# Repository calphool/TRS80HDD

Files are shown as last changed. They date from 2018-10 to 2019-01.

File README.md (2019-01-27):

# TRS80HDD
Repo for TRS-80 Model 1 Drive emulator project

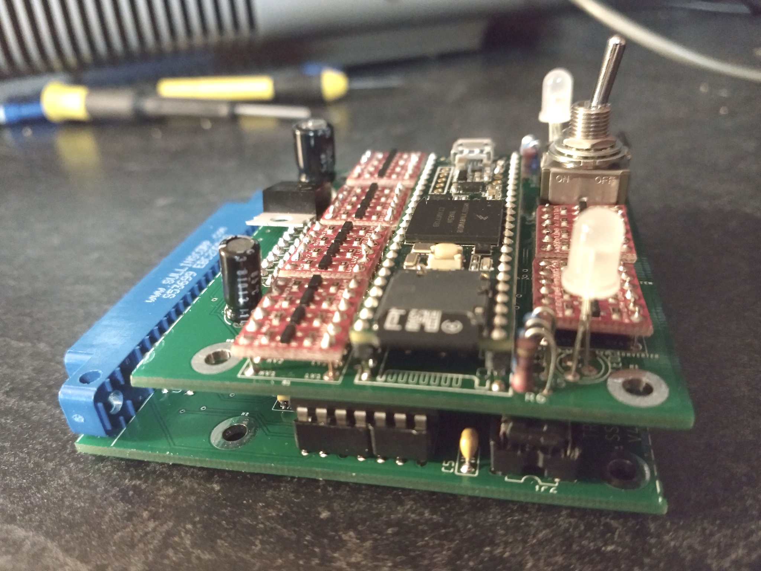
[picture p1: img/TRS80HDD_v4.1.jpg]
Version 4.1 of PCB


Here we go again.  So after I finished the graphics/sound/communications card, I started working on a new
project.  This time I'm working on interfacing the TRS-80 to a Teensy 3.6, which is an Arduino-ish microcontroller 
board.  It's a lot faster than the Arduino Uno, and has more ports.  You can use the Arduino tool chain, which is 
nice. 

Theory of Operation
===================

To understand how this card works (in theory... still working out some bugs as of December 2018), you have to 
understand how the TRS-80 expected to interface to floppy drives.  I'm in awe of what engineers in 1977 had to 
deal with to produce a working computer.  We take so much for granted today.  First of all, the TRS-80 Model 1
couldn't interface to a floppy drive unless you purchased the Expansion System.  That expansion system is 
essentially a large daughter board and a power supply.  It connected to your TRS-80 via a ribbon cable attached 
to the expansion bus on the keyboard/CPU unit.  Inside was a fairly complex set of components.  There's a real time
clock module that keeps pinging the CPU unit 40 times a second.  There's additional DRAM in there.  There's a bunch
of glue logic that allows you to connect a parallel port printer (remember those?) and a UART for (very slow) 
RS232 / modem connectivity.  Finally, there's an [FD1771](https://en.wikipedia.org/wiki/Western_Digital_FD1771) chip.
That chip is one of the first floppy disk controller chips.  It was released in 1976, and was used in various forms 
up into the 1990s.  On one side of the chip you've got an interface designed to connect to a system bus, and on the 
other side you've got an interface designed to connect to a stepper driven floppy drive.  There's glue logic in the 
Expansion System that basically memory mapped the FD1771 chip into the address space of the Z80 processor of the 
CPU unit.  You get a little keyhole interface into RAM (0x37E0 - 0x37EF) that you can read and write to, and the chip 
responds by reading/writing to the floppy by manipulating the drive spindle and the head steppers.

So, the way this emulated device works is that it has an address decoder that watches for those addresses, along with 
read and write signal lines, triggers a flip-flop that puts the Z80 processor in the CPU unit into a WAIT state, 
invokes an interrupt on the Teensy, the Teensy reads an SD card for a disk image, and emulates the intent of the 
read or write command against that disk image file.  Once the read or write is complete the Teensy kicks the flip-flop 
and the WAIT state is released.  ~~At least, that's the theory.  I'm still working through some timing issues before 
I start working in earnest on the Teensy code.  Basically I've got everything working right now except the data bus.
The data bus seems to be doing nothing at the moment, and I haven't figured out exactly what's wrong yet.~~

Build Notes
===========

January 26, 2019

Well, I bodged a 32k SRAM onto the design.  Some NEWDOS games won't work because they expect (quite reasonably) that you have 48k of RAM,
since the original TRS-80 expansion system included some RAM, and you couldn't really run a disk drive without having the extra RAM.  
Version 4.2 of the schematic and board include this enhancement.

So here's what I'm thinking about doing... I'm thinking about designing a set of three stackable boards (sort of like Arduino shields).  The 
first board just gives you 32k of extra RAM, six channel (+2 noise) audio, and your power supply.  The second adds the TMS9118 video 
(see TRS80GS) and joystick ports. The third adds the emulated disk drive.  So, you could build these boards and then snap them together as you like.

January 22, 2019

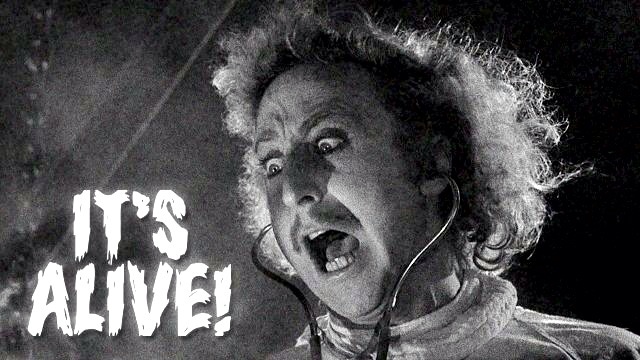
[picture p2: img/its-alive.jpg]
It's Alive!


Holy smokes.  [It's working.](https://www.youtube.com/watch?v=pcdh7HSC1nE)  I've got NEWDOS/80 v2 booting up, and it seems quite functional.  
Since I haven't implemented WRITE handling code, and only the most critical READ handling code, it's pretty fragile right now, but it's booting 
and responding to commands.  This is the v4 board, so if you're following along and want to make your own, v4 with current code is the first 
actually functioning configuration.  

January 16, 2019

Considerable gnashing of teeth has occurred over the past month, but progress has been made.  The v3 and v3.1 designs 
are basically a bust.  There has been some kind of race condition on the WR* side of the data bus, and figuring out what
was going on has been nontrivial.  Folks on the Teensy forum basically said that the problem was that I was using 
unrelated Teensy ports for my 8 data signals, and that digitalReadFast() wasn't fast enough when you used it that way.
So they suggested I redesign the circuit so that all the data lines reside in a single Teensy port, which I did....
and it made absolutely no difference... Luckily I didn't completely trust their diagnosis and I simultaneously created the 
v4 design.  The v4 design was intended to fix the race condition by implementing a latch on the 
data bus (more or less a classical output port design).  This did improve things (actually started getting data to the 
Teensy sometimes), but it wasn't reliable.  After a lot of hand wringing, someone on the Teensy forums suggested a slight 
change to my wait flip flop triggering circuit so that it triggered as soon as an interesting address appeared (as soon 
as the 37EX signal toggled) rather than waiting for both that *and* a RD* or WR* signal.  This made the circuit fairly 
predictable, though it still glitches about 1 out of every 1000 writes.  The design is available in schematic v4.1.
I'm thinking that perhaps if I swap out all the LS series chips with ALS series chips, I'll get just enough of a 
performance boost across the combined propogation delay that I can get the WR* side rock solid like the RD* side is.  We'll
see.

However, the good news is that I'm actually booting stuff now.

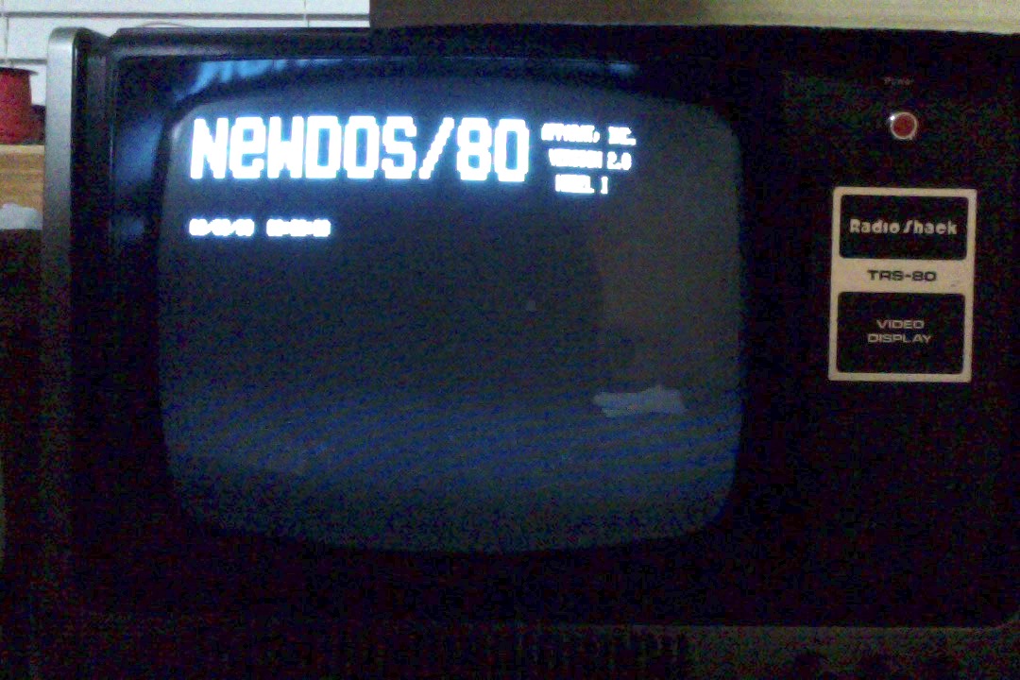
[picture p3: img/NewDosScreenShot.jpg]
NEWDOS screen shot


~~There's still *some* kind of bug in my emulation, because it gets loaded and then doesn't give me control, and keeps 
trying to reload.  I know that the problem is somehow related to the clock signal, because when I shut it off it loads and
then just sits there.  If I turn it on, it loads, and then reloads, in a loop.  So I'm guessing I need to do something 
besides just turn the clock on, but I don't know what it's expecting just yet.  It could be as simple as making sure that
I'm handling the FD1771 status register correctly when I get to the end of the boot cycle.  I do think I've got a few bugs left 
in the status register handling, and I think I might have an off-by-one problem in handling sector read commands.  So either 
one of those problems could be the source of my rebooting problem.  However, I'm really close, and that makes me super happy.~~

With some help from someone on reddit, I was able to get it booting.  It's related to the fact that I'm using JV1 disk images, 
which apparently don't encode all the data that was on the original disks.  Apparently part of what was missing was a code that 
can be returned in the status register that indicates to the operating system that what it's reading represents directory data.
Since my disk images don't have that info, I guess my code is supposed to assume track 17 is the directory data, so it was 
as simple as forcing the status register to OR 0x20 with whatever it's already doing if the track is 17.

It's still not quite working right, because I can't do a DIR command (says "device not available"), but it's booting and semi-
usable now.  Now I just need to figure out why I can't do a DIR command.  I'm beginning to wonder if I shouldn't just figure 
out how to port the applicable code from SDLTRS over to the Teensy.  Then I'd be able to support several disk formats, and 
these kinds of strange little details would be handled for me, rather than me slowly finding them one by one.  I've avoided 
trying the port exercise, because I wasn't sure if the C compilers are compatible, or if I'll end up with strange data size 
issues or endian issues.  I might make one quick stab at getting it working without the porting effort, and then if it doesn't
work I'll dive into that.

--------------------------------------------------------

December 17, 2018

Well I'm working on version 2 of this project.  I found a copy of Byte Magazine from the late 70s that included a 
schematic from Steve Ciarcia for his Disk-80 project.  I decided to abandon my home grown address decoder and 
switched to his design.  The v3 of the schematic represents that.  Upon assembly, it didn't really work, and I 
was scratching my head.  I reached out to Peter Bartlett, who is the rock star that designed the MISE and M3SE 
boards that are light years beyond what my little projects are capable of.  He took a look at my schematics and 
helped me realize that I used a 74LS241 for my data buffer, and I probably meant to use a 74LS244.  The difference 
is that 74LS241 has four bits that are controlled by a positive enable pin, and the other four are controlled by 
a negative enable pin.  So I ordered some 74LS244's and we'll see where that gets me.

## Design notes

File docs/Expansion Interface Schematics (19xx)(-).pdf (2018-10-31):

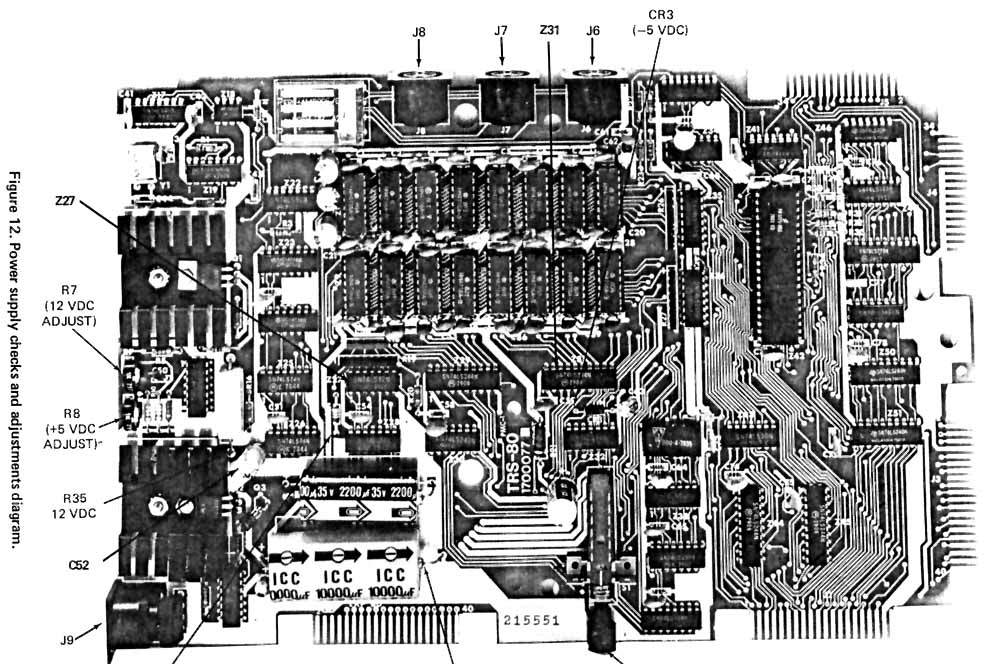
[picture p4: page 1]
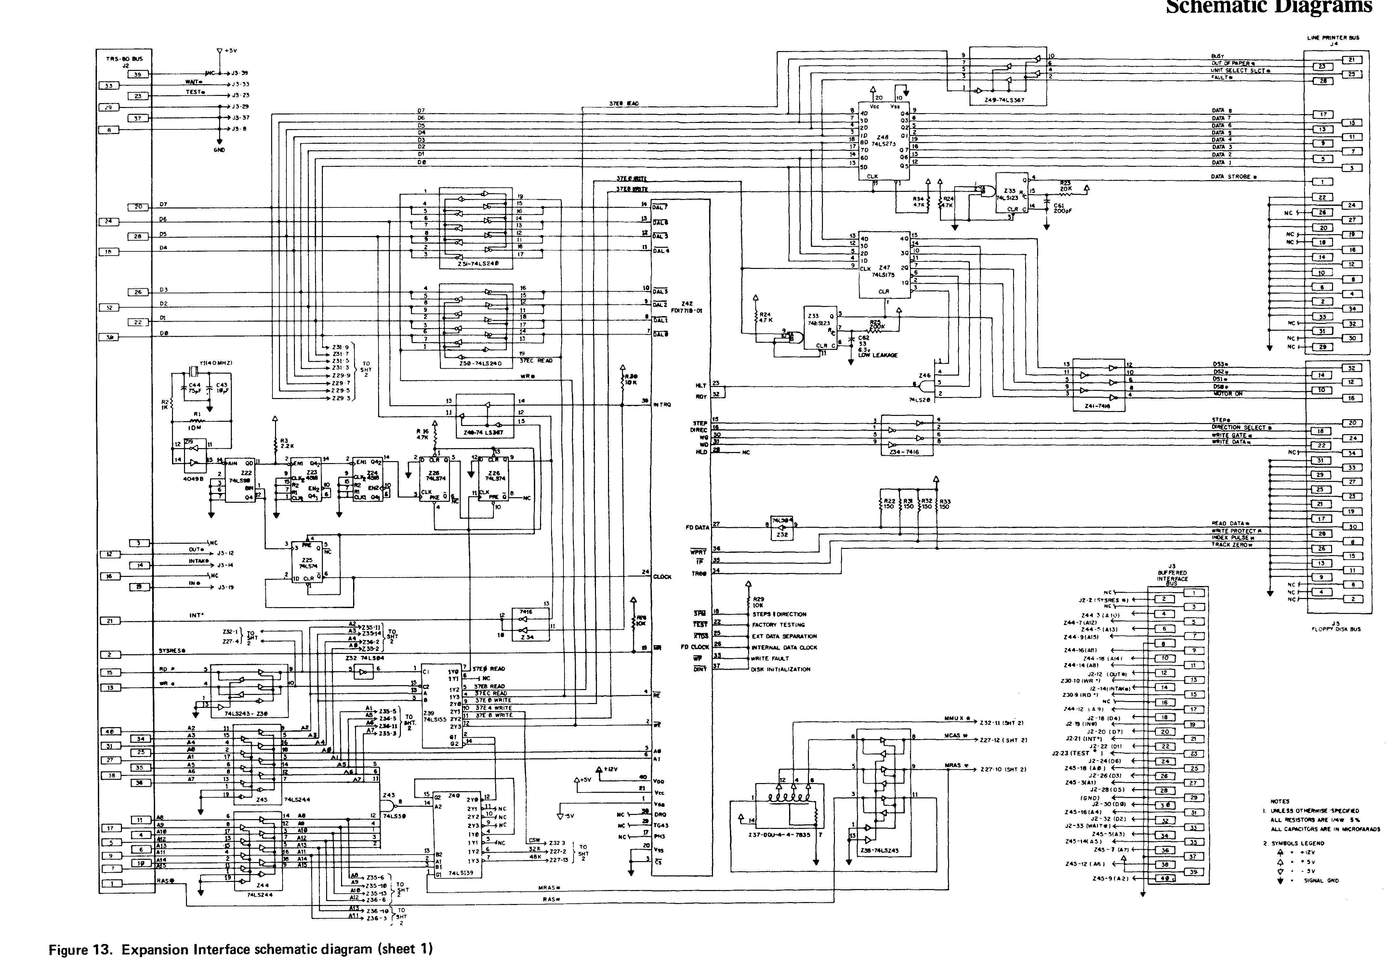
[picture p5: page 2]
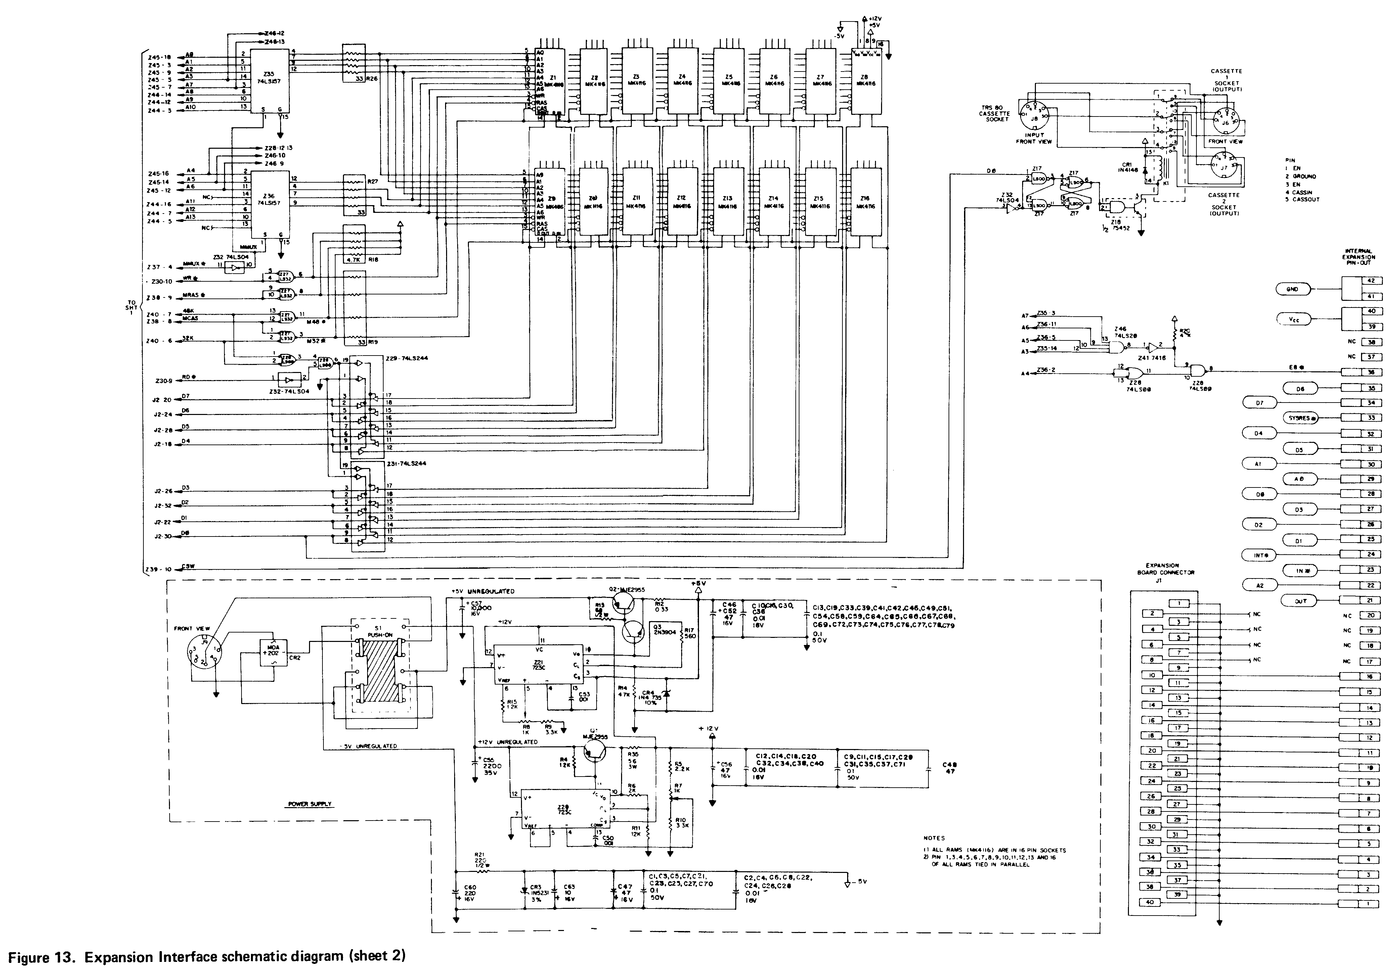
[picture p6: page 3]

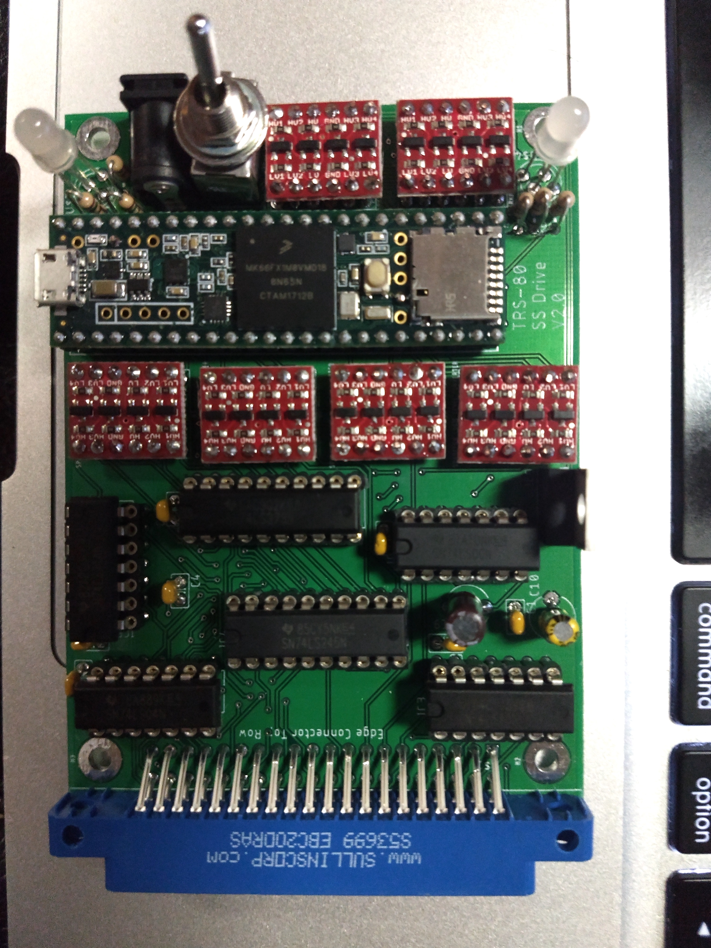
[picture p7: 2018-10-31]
img/TRS80HDD_v2.jpg

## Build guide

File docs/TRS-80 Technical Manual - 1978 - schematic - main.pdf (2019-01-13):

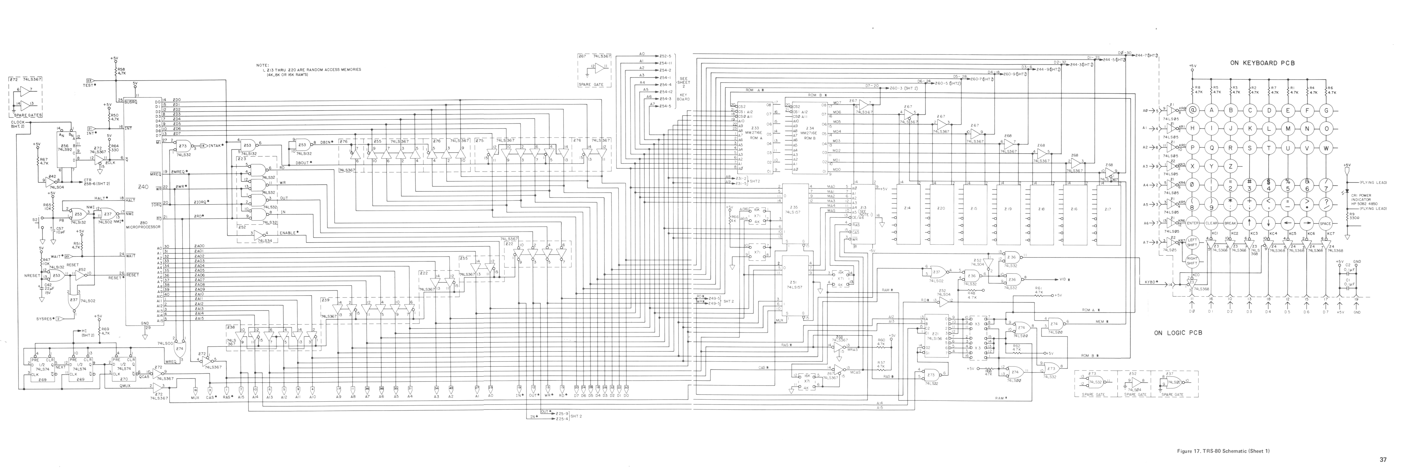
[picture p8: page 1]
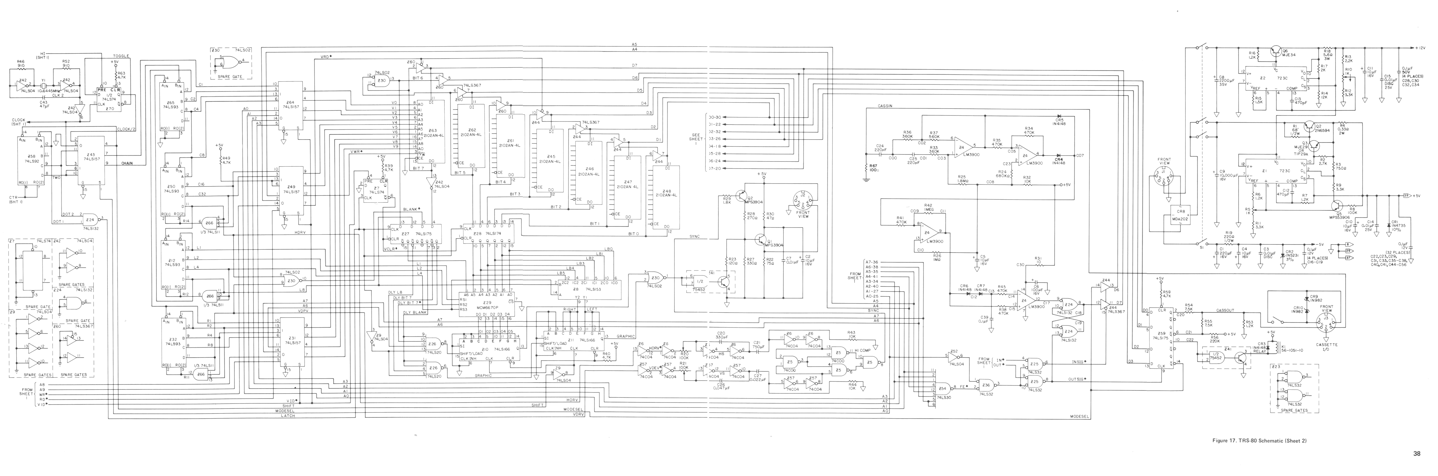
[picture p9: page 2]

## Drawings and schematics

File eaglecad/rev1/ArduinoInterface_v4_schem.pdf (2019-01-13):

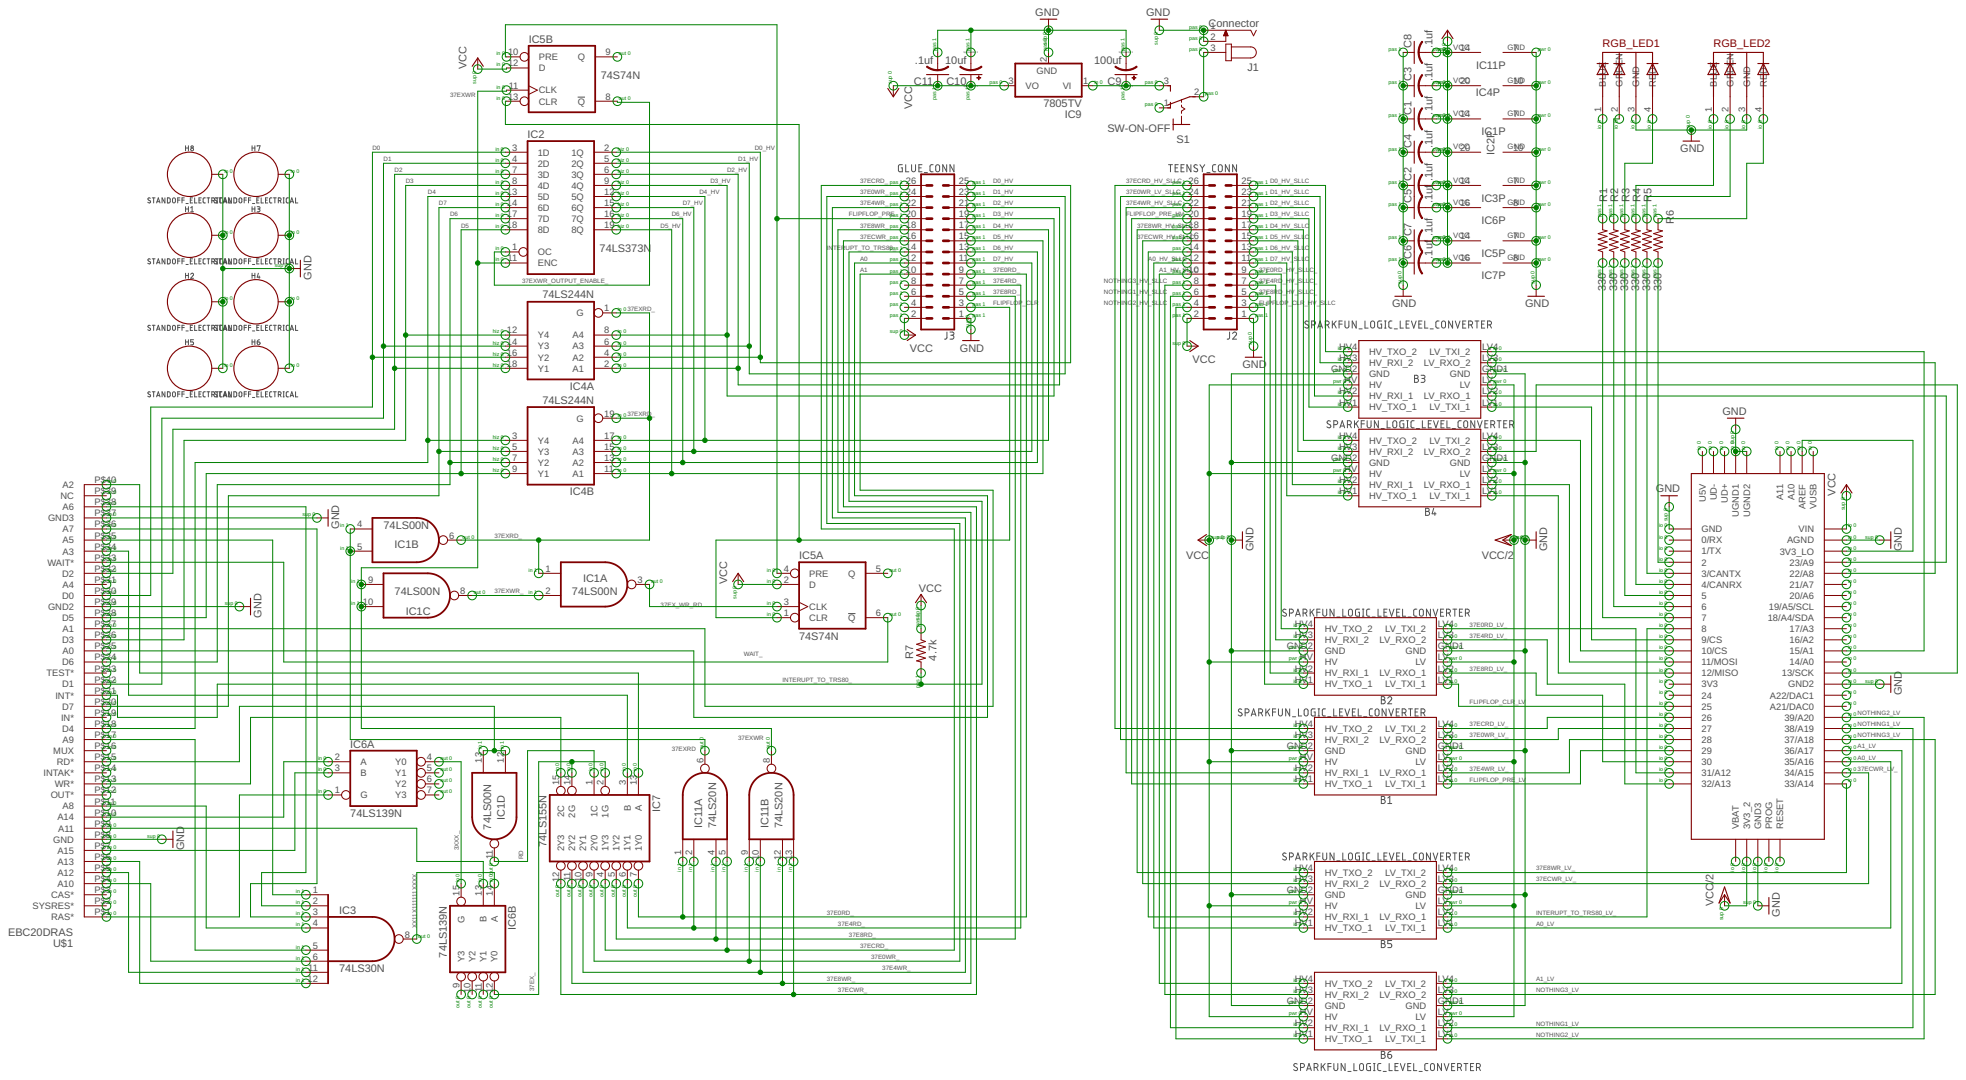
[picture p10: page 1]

D2 | 7 in 0 | 6 hiz 0 | D2_HV
D3 | 8 in 0 | 9 hiz 0 | D3_HV

14 hiz 0 | 6 A4 in 0
16 hiz 0 | | 4 A3 in 0
18 hiz 0 | | 2 A2 in 0

io 0 sup 0

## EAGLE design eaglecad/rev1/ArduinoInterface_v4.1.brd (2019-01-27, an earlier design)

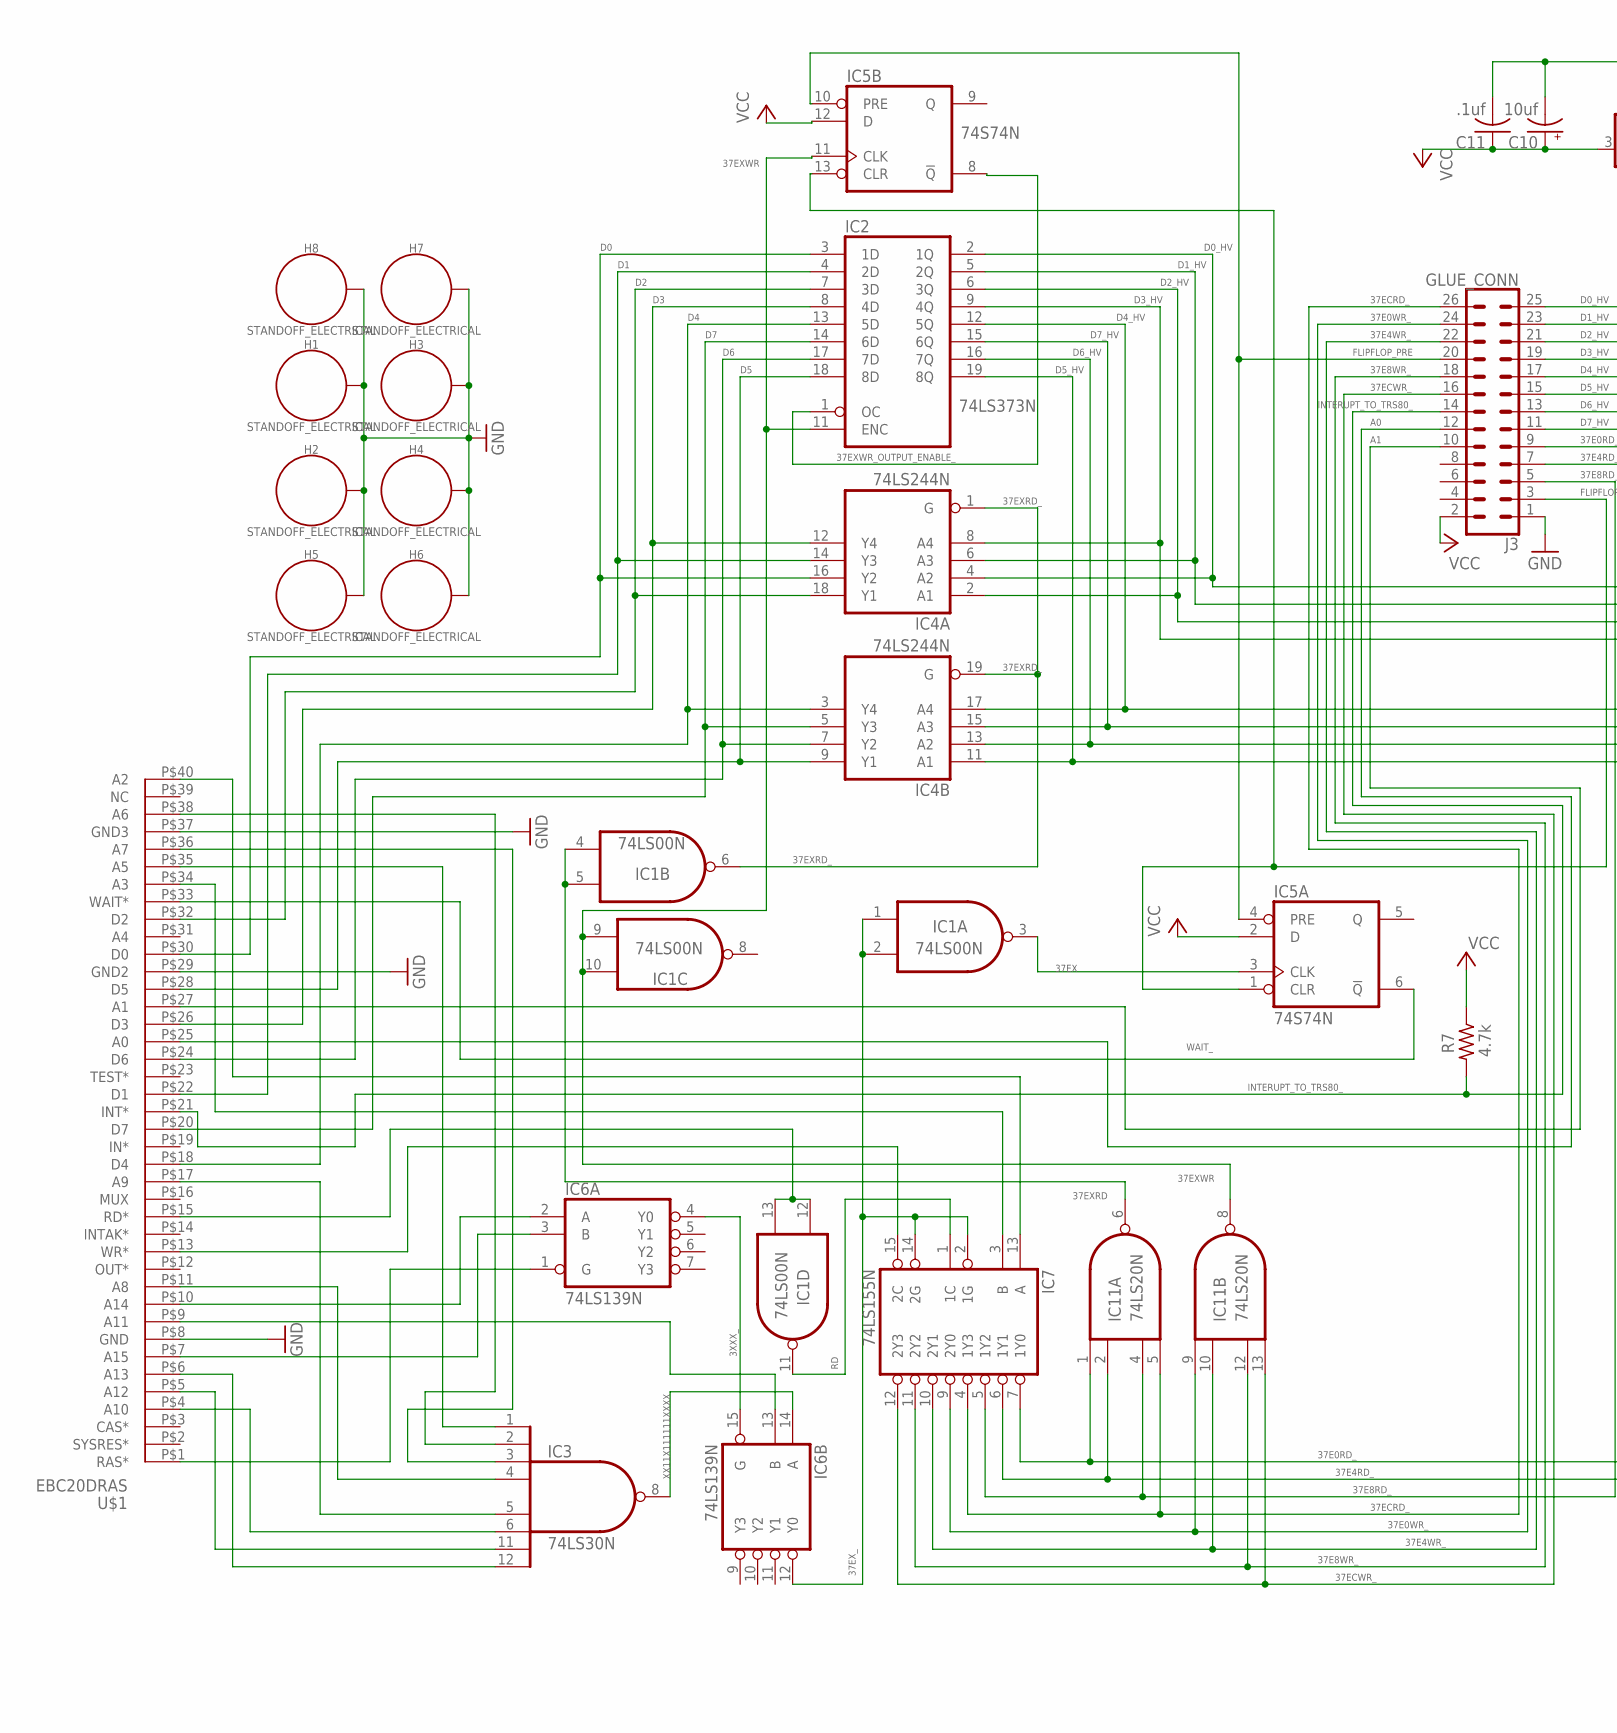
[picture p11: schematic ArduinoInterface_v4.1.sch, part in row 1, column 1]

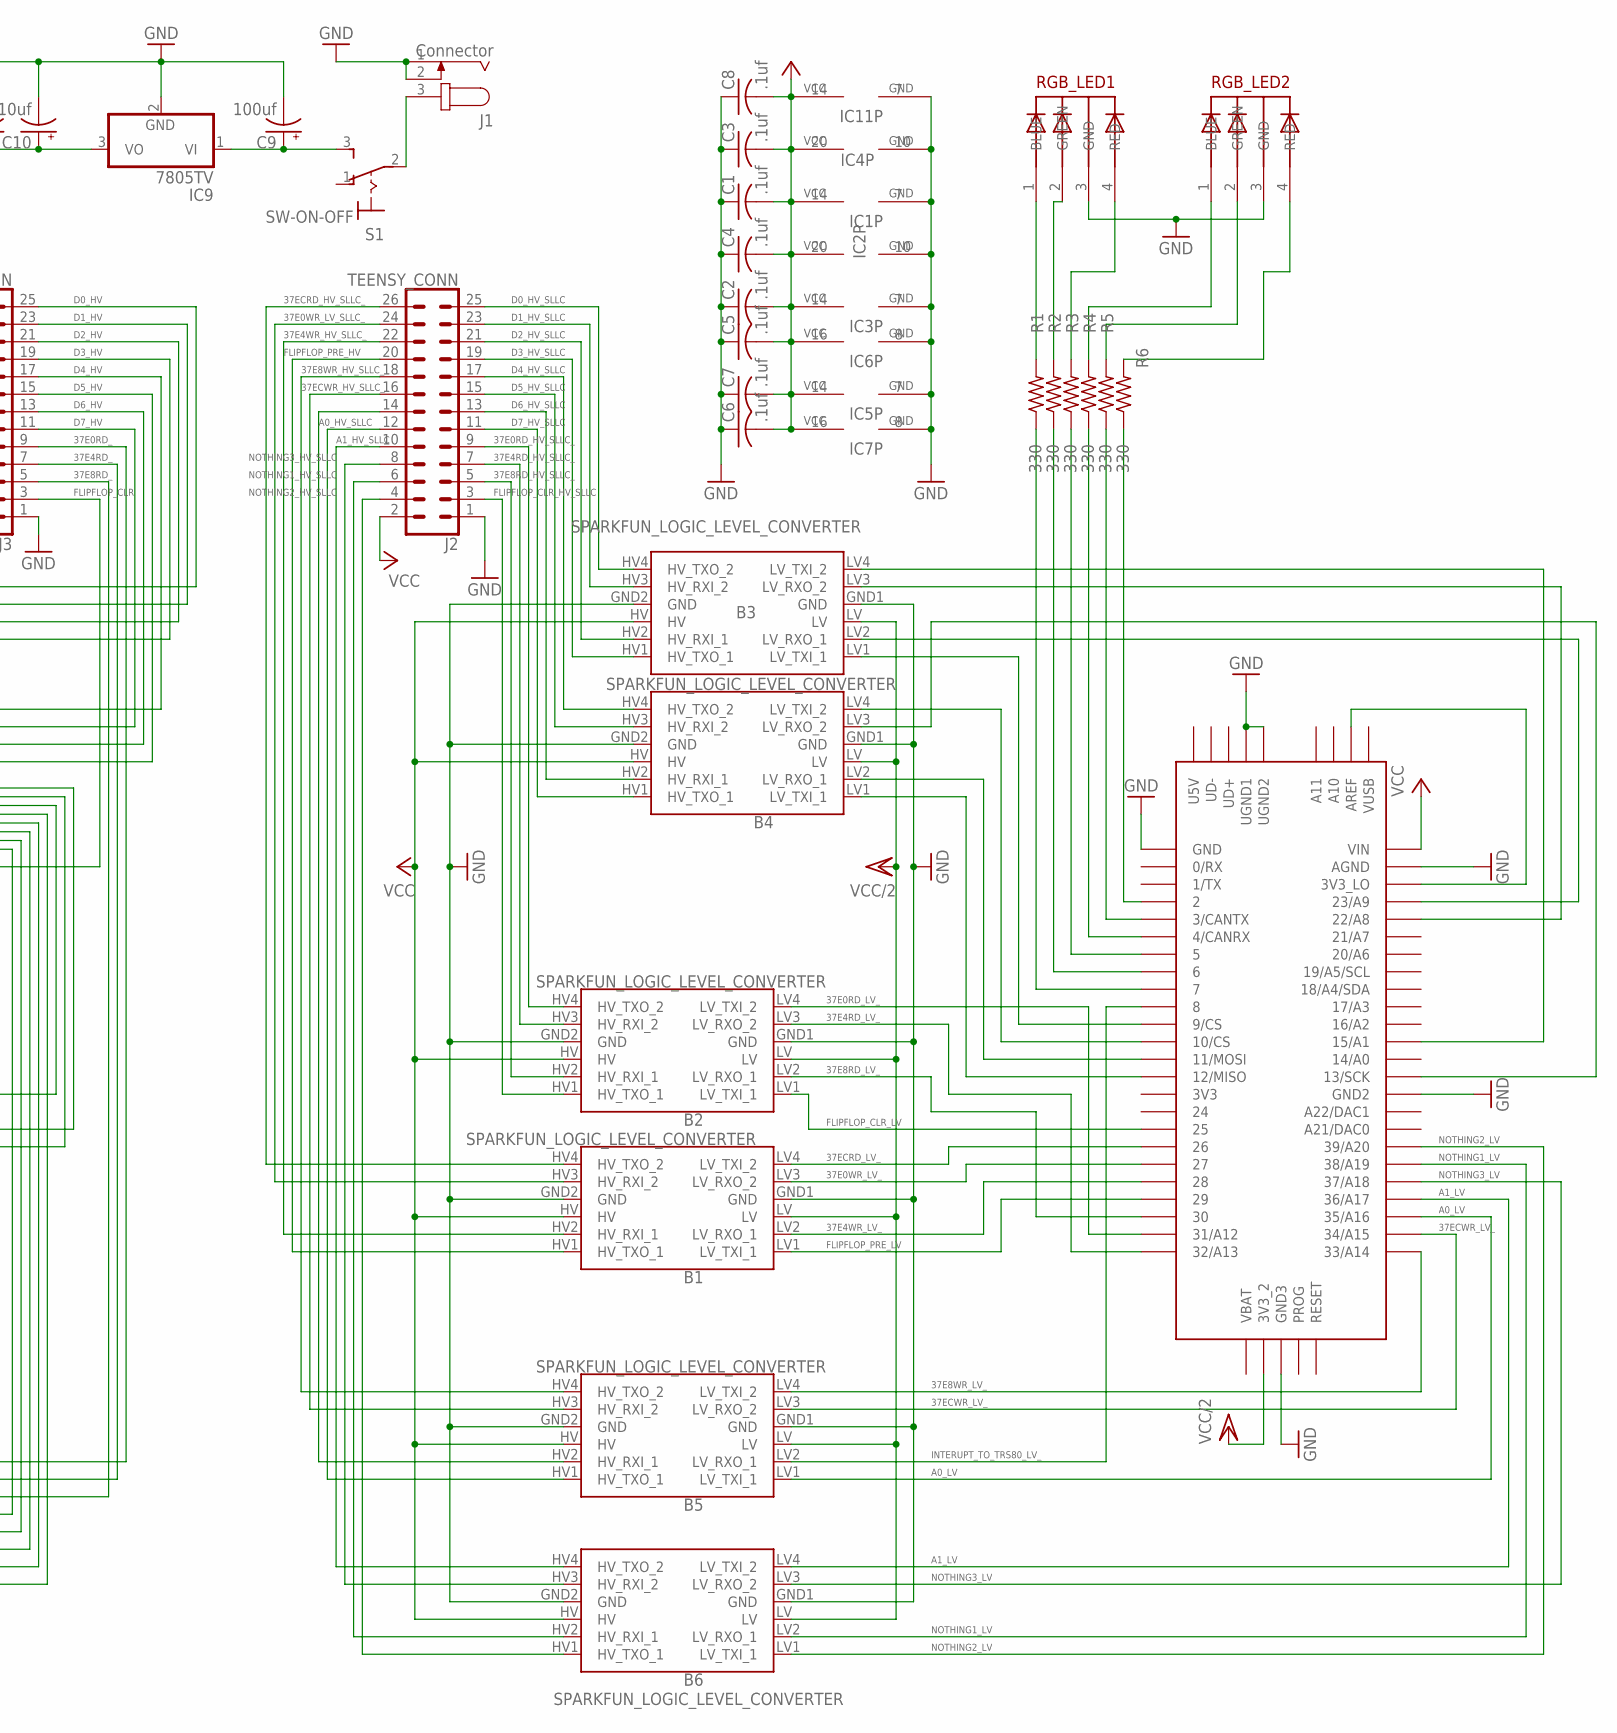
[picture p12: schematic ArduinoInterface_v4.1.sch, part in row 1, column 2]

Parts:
B1, B2, B3, B4, B5, B6: SPARKFUN_LOGIC_LEVEL_CONVERTER
C1, C2, C3, C4, C5, C6, C7, C8, C11: .1uf; C025-025X050
C9: 100uf; E5-6
C10: 10uf; E5-6
H1, H2, H3, H4, H5, H6, H7, H8: STANDOFF_ELECTRICAL; STANDOFF-ELECTRICAL
IC1: 74LS00N; DIL14
IC2: 74LS373N; DIL20
IC3: 74LS30N; DIL14
IC4: 74LS244N; DIL20
IC5: 74S74N; DIL14
IC6: 74LS139N; DIL16
IC7: 74LS155N; DIL16
IC9: 7805TV; TO220V
IC11: 74LS20N; DIL14
J1: Connector; SPC4077
J2: TEENSY_CONN; 2X13
J3: GLUE_CONN; 2X13
R1, R2, R3, R4, R5, R6: 330; 0204V
R7: 4.7k; 0204V
RGB_LED1, RGB_LED2: 5MMRGBLED; LED5MMRGB
S1: SW-ON-OFF; M9040P
U$1: EBC20DRAS
U$2: TEENSY_3.5/3.6

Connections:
3XXX_: IC6.4 (Y0), IC6.15 (G)
9V: C9.+, IC9.1 (VI), S1.3 (S)
9V_TO_SW: J1.3, S1.2
37E0RD_: IC7.7 (1Y0), IC11.1 (I0), J3.9
37E0RD_HV_SLLC_: B2.HV4 (HV_TXO_2), J2.9
37E0RD_LV_: B2.LV4 (LV_TXI_2), U$2.31/A12
37E0WR_: IC7.9 (2Y0), IC11.9 (I0), J3.24
37E0WR_LV_: B1.LV3 (LV_RXO_2), U$2.27
37E0WR_LV_SLLC_: B1.HV3 (HV_RXI_2), J2.24
37E4RD_: IC7.6 (1Y1), IC11.2 (I1), J3.7
37E4RD_HV_SLLC_: B2.HV3 (HV_RXI_2), J2.7
37E4RD_LV_: B2.LV3 (LV_RXO_2), U$2.32/A13
37E4WR_: IC7.10 (2Y1), IC11.10 (I1), J3.22
37E4WR_HV_SLLC_: B1.HV2 (HV_RXI_1), J2.22
37E4WR_LV_: B1.LV2 (LV_RXO_1), U$2.28
37E8RD_: IC7.5 (1Y2), IC11.4 (I2), J3.5
37E8RD_HV_SLLC_: B2.HV2 (HV_RXI_1), J2.5
37E8RD_LV_: B2.LV2 (LV_RXO_1), U$2.30
37E8WR_: IC7.11 (2Y2), IC11.12 (I2), J3.18
37E8WR_HV_SLLC_: B5.HV4 (HV_TXO_2), J2.18
37E8WR_LV_: B5.LV4 (LV_TXI_2), U$2.33/A14
37ECRD_: IC7.4 (1Y3), IC11.5 (I3), J3.26
37ECRD_HV_SLLC_: B1.HV4 (HV_TXO_2), J2.26
37ECRD_LV_: B1.LV4 (LV_TXI_2), U$2.26
37ECWR_: IC7.12 (2Y3), IC11.13 (I3), J3.16
37ECWR_HV_SLLC_: B5.HV3 (HV_RXI_2), J2.16
37ECWR_LV_: B5.LV3 (LV_RXO_2), U$2.34/A15
37EX: IC1.3 (O), IC5.3 (CLK)
37EXRD: IC1.4 (I0), IC1.5 (I1), IC11.6 (O)
37EXRD_: IC1.6 (O), IC4.1 (G), IC4.19 (G)
37EXWR: IC1.9 (I0), IC1.10 (I1), IC2.11 (ENC), IC5.11 (CLK), IC11.8 (O)
37EXWR_OUTPUT_ENABLE_: IC2.1 (OC), IC5.8 (!Q)
37EX_: IC1.1 (I0), IC1.2 (I1), IC6.12 (Y0), IC7.2 (1G), IC7.14 (2G)
A0: J3.12, U$1.P$25 (A0)
A0_HV_SLLC: B5.HV1 (HV_TXO_1), J2.12
A0_LV: B5.LV1 (LV_TXI_1), U$2.35/A16
A1: J3.10, U$1.P$27 (A1)
A1_HV_SLLC: B6.HV4 (HV_TXO_2), J2.10
A1_LV: B6.LV4 (LV_TXI_2), U$2.36/A17
A2: IC7.13 (A), U$1.P$40 (A2)
A3: IC7.3 (B), U$1.P$34 (A3)
A5: IC3.1 (I0), U$1.P$35 (A5)
A6: IC3.2 (I1), U$1.P$38 (A6)
A7: IC3.3 (I2), U$1.P$36 (A7)
A8: IC3.4 (I3), U$1.P$11 (A8)
A9: IC3.5 (I4), U$1.P$17 (A9)
A10: IC3.6 (I5), U$1.P$4 (A10)
A11: IC6.13 (B), U$1.P$9 (A11)
A12: IC3.11 (I6), U$1.P$5 (A12)
A13: IC3.12 (I7), U$1.P$6 (A13)
A14: IC6.2 (A), U$1.P$10 (A14)
A15: IC6.3 (B), U$1.P$7 (A15)
D0: IC2.3 (1D), IC4.16 (Y2), U$1.P$30 (D0)
D0_HV: IC2.2 (1Q), IC4.4 (A2), J3.25
D0_HV_SLLC: B3.HV4 (HV_TXO_2), J2.25
D0_LV: B3.LV4 (LV_TXI_2), U$2.15/A1
D1: IC2.4 (2D), IC4.14 (Y3), U$1.P$22 (D1)
D1_HV: IC2.5 (2Q), IC4.6 (A3), J3.23
D1_HV_SLLC: B3.HV3 (HV_RXI_2), J2.23
D1_LV: B3.LV3 (LV_RXO_2), U$2.22/A8
D2: IC2.7 (3D), IC4.18 (Y1), U$1.P$32 (D2)
D2_HV: IC2.6 (3Q), IC4.2 (A1), J3.21
D2_HV_SLLC: B3.HV2 (HV_RXI_1), J2.21
D2_LV: B3.LV2 (LV_RXO_1), U$2.23/A9
D3: IC2.8 (4D), IC4.12 (Y4), U$1.P$26 (D3)
D3_HV: IC2.9 (4Q), IC4.8 (A4), J3.19
D3_HV_SLLC: B3.HV1 (HV_TXO_1), J2.19
D3_LV: B3.LV1 (LV_TXI_1), U$2.9/CS
D4: IC2.13 (5D), IC4.3 (Y4), U$1.P$18 (D4)
D4_HV: IC2.12 (5Q), IC4.17 (A4), J3.17
D4_HV_SLLC: B4.HV4 (HV_TXO_2), J2.17
D4_LV: B4.LV4 (LV_TXI_2), U$2.10/CS
D5: IC2.18 (8D), IC4.9 (Y1), U$1.P$28 (D5)
D5_HV: IC2.19 (8Q), IC4.11 (A1), J3.15
D5_HV_SLLC: B4.HV3 (HV_RXI_2), J2.15
D5_LV: B4.LV3 (LV_RXO_2), U$2.13/SCK
D6: IC2.17 (7D), IC4.7 (Y2), U$1.P$24 (D6)
D6_HV: IC2.16 (7Q), IC4.13 (A2), J3.13
D6_HV_SLLC: B4.HV2 (HV_RXI_1), J2.13
D6_LV: B4.LV2 (LV_RXO_1), U$2.11/MOSI
D7: IC2.14 (6D), IC4.5 (Y3), U$1.P$20 (D7)
D7_HV: IC2.15 (6Q), IC4.15 (A3), J3.11
D7_HV_SLLC: B4.HV1 (HV_TXO_1), J2.11
D7_LV: B4.LV1 (LV_TXI_1), U$2.12/MISO
FLIPFLOP_CLR: IC5.1 (CLR), IC5.13 (CLR), J3.3
FLIPFLOP_CLR_HV_SLLC: B2.HV1 (HV_TXO_1), J2.3
FLIPFLOP_CLR_LV: B2.LV1 (LV_TXI_1), U$2.25
FLIPFLOP_PRE: IC5.4 (PRE), IC5.10 (PRE), J3.20
FLIPFLOP_PRE_HV: B1.HV1 (HV_TXO_1), J2.20
FLIPFLOP_PRE_LV: B1.LV1 (LV_TXI_1), U$2.29
GND: B1.GND1 (GND), B1.GND2 (GND), B2.GND1 (GND), B2.GND2 (GND), B3.GND1 (GND), B3.GND2 (GND), B4.GND1 (GND), B4.GND2 (GND), B5.GND1 (GND), B5.GND2 (GND), B6.GND1 (GND), B6.GND2 (GND), C1.1, C2.1, C3.1, C4.1, C5.1, C6.1, C7.1, C8.1, C9.-, C10.-, C11.2, H1.P1, H2.P1, H3.P1, H4.P1, H5.P1, H6.P1, H7.P1, H8.P1, IC1.7 (GND), IC2.10 (GND), IC3.7 (GND), IC4.10 (GND), IC5.7 (GND), IC6.8 (GND), IC7.8 (GND), IC9.2 (GND), IC11.7 (GND), J1.1, J1.2, J2.1, J3.1, RGB_LED1.3 (GND), RGB_LED2.3 (GND), U$1.P$8 (GND), U$1.P$29 (GND2), U$1.P$37 (GND3), U$2.AGND, U$2.GND, U$2.GND2, U$2.GND3, U$2.UGND1, U$2.UGND2
INTERUPT_TO_TRS80_: J3.14, R7.2, U$1.P$21 (INT*)
INTERUPT_TO_TRS80_HV_SLLC_: B5.HV2 (HV_RXI_1), J2.14
INTERUPT_TO_TRS80_LV_: B5.LV2 (LV_RXO_1), U$2.8
unnamed: U$2.3V3_LO, U$2.AREF
unnamed: R2.2, RGB_LED1.2 (GREEN)
unnamed: R6.1, U$2.2
unnamed: R5.1, U$2.3/CANTX
unnamed: R4.1, U$2.4/CANRX
unnamed: R3.1, U$2.5
unnamed: R2.1, U$2.6
unnamed: R1.1, U$2.7
unnamed: R1.2, RGB_LED1.1 (BLUE)
unnamed: R3.2, RGB_LED1.4 (RED)
unnamed: R4.2, RGB_LED2.1 (BLUE)
unnamed: R5.2, RGB_LED2.2 (GREEN)
unnamed: R6.2, RGB_LED2.4 (RED)
NOTHING1_HV_SLLC: B6.HV2 (HV_RXI_1), J2.6
NOTHING1_LV: B6.LV2 (LV_RXO_1), U$2.38/A19
NOTHING2_HV_SLLC: B6.HV1 (HV_TXO_1), J2.4
NOTHING2_LV: B6.LV1 (LV_TXI_1), U$2.39/A20
NOTHING3_HV_SLLC: B6.HV3 (HV_RXI_2), J2.8
NOTHING3_LV: B6.LV3 (LV_RXO_2), U$2.37/A18
RAS_: IC6.1 (G), U$1.P$1 (RAS*)
RD: IC1.11 (O), IC7.1 (1C)
RD_: IC1.12 (I0), IC1.13 (I1), U$1.P$15 (RD*)
VCC: B1.HV, B2.HV, B3.HV, B4.HV, B5.HV, B6.HV, C1.2, C2.2, C3.2, C4.2, C5.2, C6.2, C7.2, C8.2, C10.+, C11.1, IC1.14 (VCC), IC2.20 (VCC), IC3.14 (VCC), IC4.20 (VCC), IC5.2 (D), IC5.12 (D), IC5.14 (VCC), IC6.16 (VCC), IC7.16 (VCC), IC9.3 (VO), IC11.14 (VCC), J2.2, J3.2, R7.1, U$2.VIN
VCC/2: B1.LV, B2.LV, B3.LV, B4.LV, B5.LV, B6.LV, U$2.3V3_2
WAIT_: IC5.6 (!Q), U$1.P$33 (WAIT*)
WR_: IC7.15 (2C), U$1.P$13 (WR*)
XX11X111111XXXX: IC3.8 (O), IC6.14 (A)

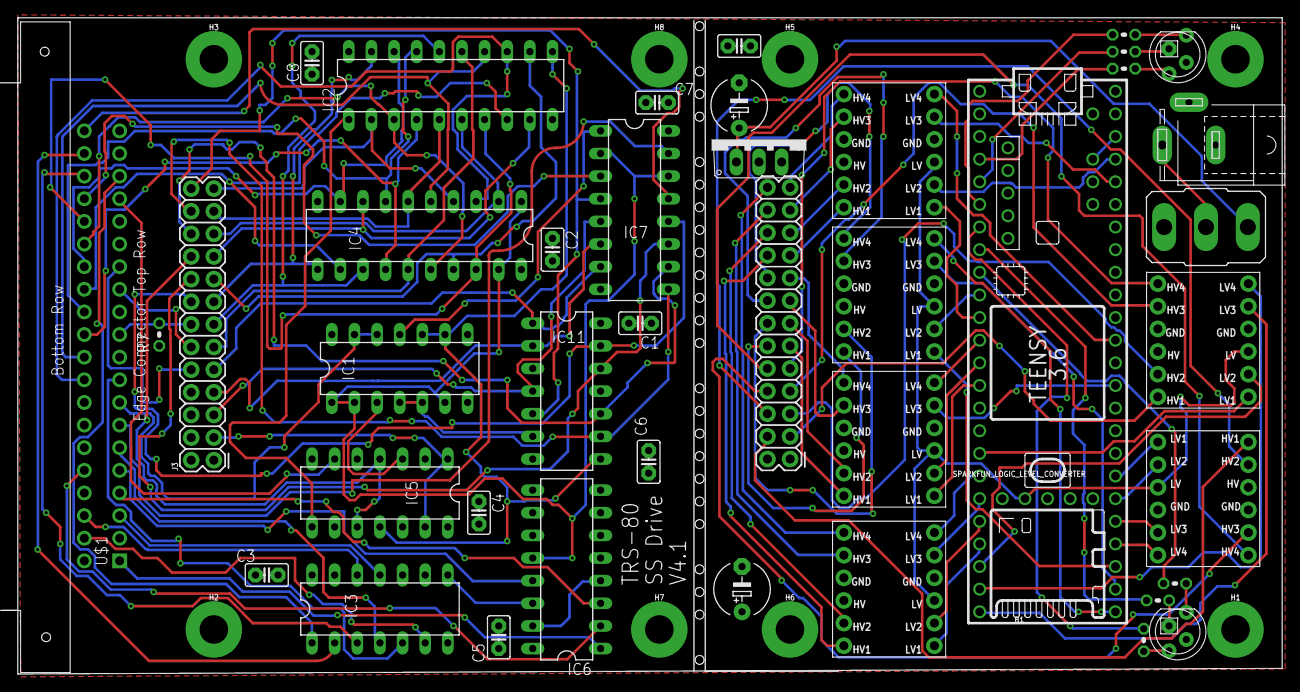
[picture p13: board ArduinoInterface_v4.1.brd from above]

Board: 2 copper layers, 141.9 x 73.6 mm, 49 parts (0 on the bottom side), 121 nets.

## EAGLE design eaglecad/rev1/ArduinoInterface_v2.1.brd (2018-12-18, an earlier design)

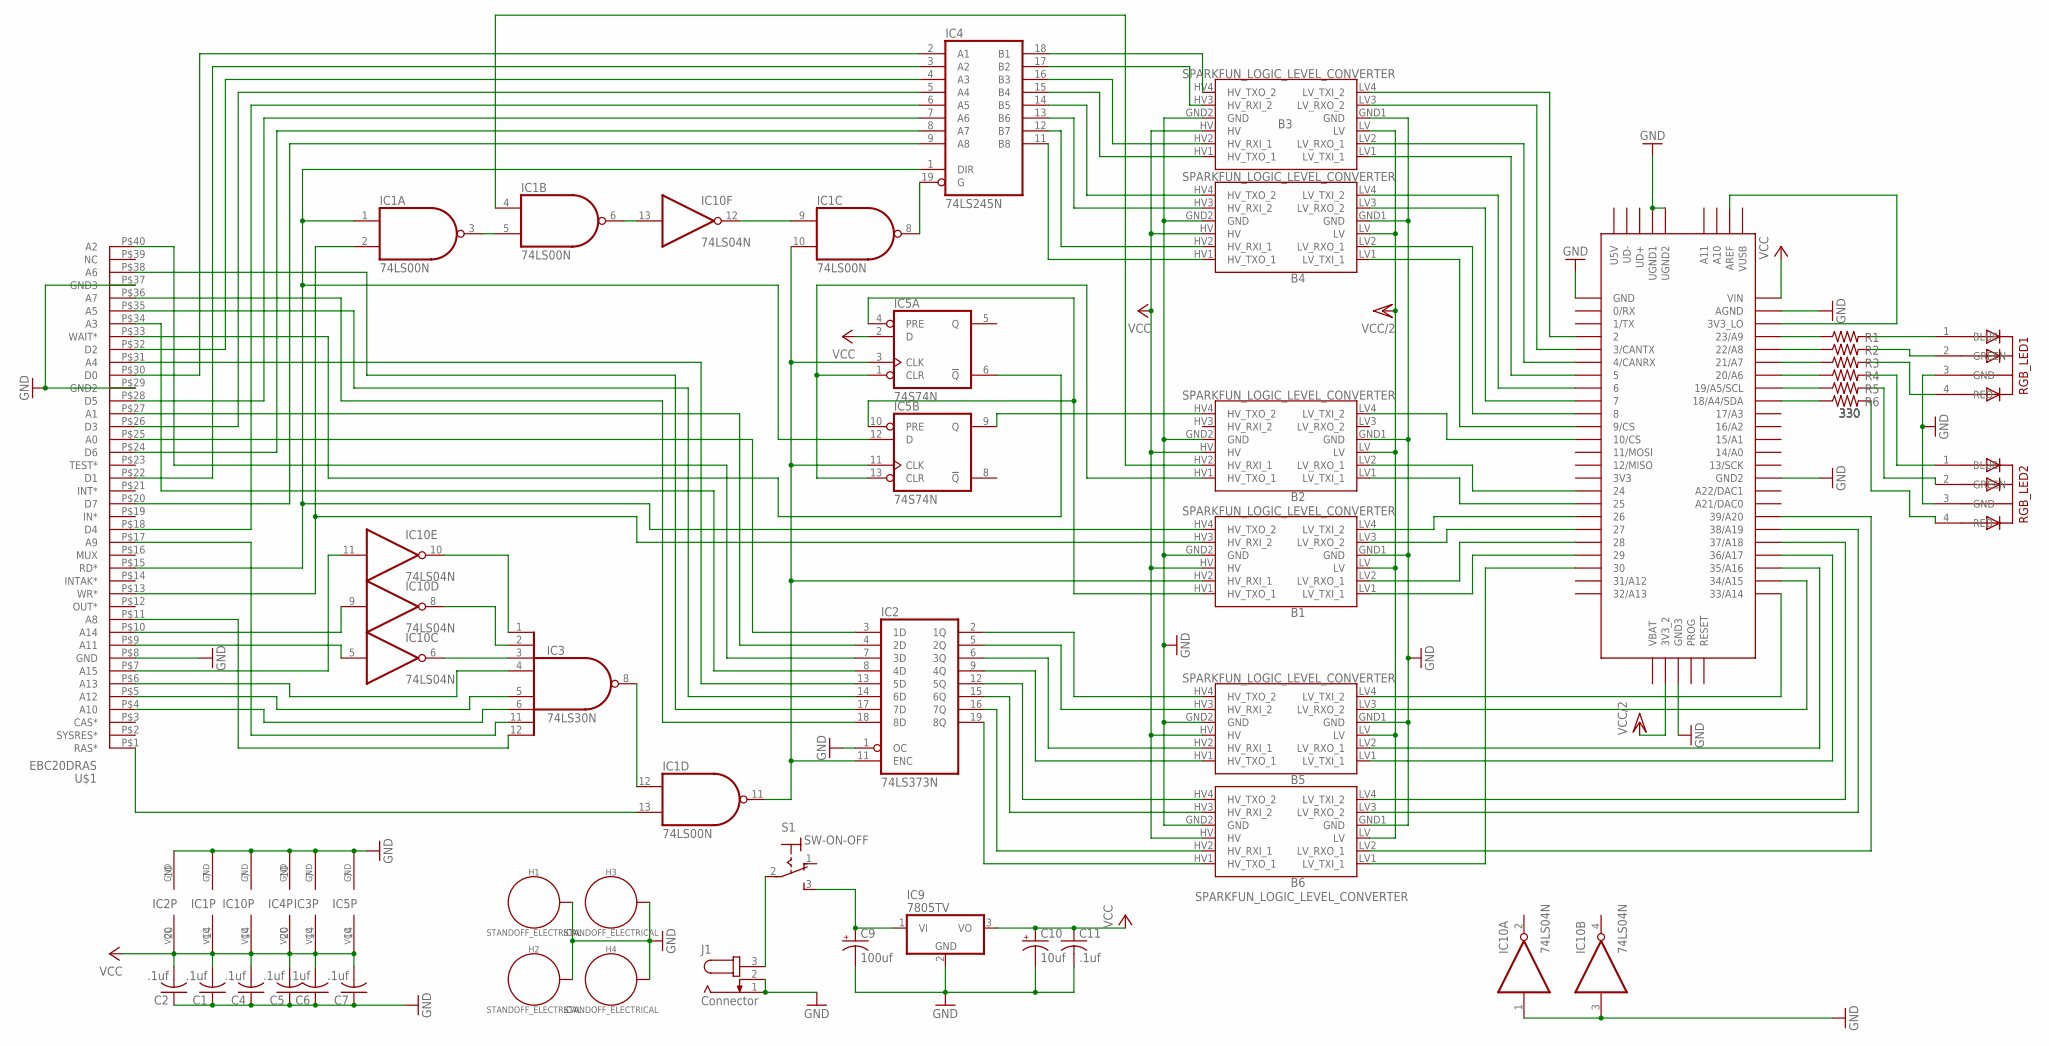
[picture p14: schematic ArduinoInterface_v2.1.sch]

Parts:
B1, B2, B3, B4, B5, B6: SPARKFUN_LOGIC_LEVEL_CONVERTER
C1, C2, C4, C5, C6, C7, C11: .1uf; C025-025X050
C9: 100uf; E5-6
C10: 10uf; E5-6
H1, H2, H3, H4: STANDOFF_ELECTRICAL; STANDOFF-ELECTRICAL
IC1: 74LS00N; DIL14
IC2: 74LS373N; DIL20
IC3: 74LS30N; DIL14
IC4: 74LS245N; DIL20
IC5: 74S74N; DIL14
IC9: 7805TV; TO220V
IC10: 74LS04N; DIL14
J1: Connector; SPC4077
R1, R2, R3, R4, R5, R6: 330; 0204V
RGB_LED1, RGB_LED2: 5MMRGBLED; LED5MMRGB
S1: SW-ON-OFF; M9040P
U$1: EBC20DRAS
U$2: TEENSY_3.5/3.6

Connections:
A0: IC2.3 (1D), U$1.P$25 (A0)
A0_AFTER_LATCH: B5.HV4 (HV_TXO_2), IC2.2 (1Q)
A0_LV: B5.LV4 (LV_TXI_2), U$2.33/A14
A1: IC2.4 (2D), U$1.P$27 (A1)
A1_AFTER_LATCH: B5.HV3 (HV_RXI_2), IC2.5 (2Q)
A1_LV: B5.LV3 (LV_RXO_2), U$2.34/A15
A2: IC2.7 (3D), U$1.P$40 (A2)
A2_AFTER_LATCH: B5.HV2 (HV_RXI_1), IC2.6 (3Q)
A2_LV: B5.LV2 (LV_RXO_1), U$2.35/A16
A3: IC2.8 (4D), U$1.P$34 (A3)
A3_AFTER_LATCH: B5.HV1 (HV_TXO_1), IC2.9 (4Q)
A3_LV: B5.LV1 (LV_TXI_1), U$2.36/A17
A4: IC2.13 (5D), U$1.P$31 (A4)
A4_AFTER_LATCH: B6.HV4 (HV_TXO_2), IC2.12 (5Q)
A4_LV: B6.LV4 (LV_TXI_2), U$2.37/A18
A5: IC2.14 (6D), U$1.P$35 (A5)
A5_AFTER_LATCH: B6.HV3 (HV_RXI_2), IC2.15 (6Q)
A5_LV: B6.LV3 (LV_RXO_2), U$2.38/A19
A6: IC2.17 (7D), U$1.P$38 (A6)
A6_AFTER_LATCH: B6.HV2 (HV_RXI_1), IC2.16 (7Q)
A6_LV: B6.LV2 (LV_RXO_1), U$2.39/A20
A7: IC2.18 (8D), U$1.P$36 (A7)
A7_AFTER_LATCH: B6.HV1 (HV_TXO_1), IC2.19 (8Q)
A7_LV: B6.LV1 (LV_TXI_1), U$2.30
A8: IC3.12 (I7), U$1.P$11 (A8)
A9: IC3.11 (I6), U$1.P$17 (A9)
A10: IC3.6 (I5), U$1.P$4 (A10)
A11: IC10.5 (I), U$1.P$9 (A11)
A12: IC3.5 (I4), U$1.P$5 (A12)
A13: IC3.4 (I3), U$1.P$6 (A13)
A15: IC10.11 (I), U$1.P$7 (A15)
D0: IC4.2 (A1), U$1.P$30 (D0)
D0_LV: B3.LV4 (LV_TXI_2), U$2.2
D1: IC4.3 (A2), U$1.P$22 (D1)
D1_LV: B3.LV3 (LV_RXO_2), U$2.3/CANTX
D2: IC4.4 (A3), U$1.P$32 (D2)
D2_HV: B3.HV2 (HV_RXI_1), IC4.16 (B3)
D2_LV: B3.LV2 (LV_RXO_1), U$2.4/CANRX
D3: IC4.5 (A4), U$1.P$26 (D3)
D3_HV: B3.HV1 (HV_TXO_1), IC4.15 (B4)
D3_LV: B3.LV1 (LV_TXI_1), U$2.5
D4: IC4.6 (A5), U$1.P$18 (D4)
D4_HV: B4.HV4 (HV_TXO_2), IC4.14 (B5)
D4_LV: B4.LV4 (LV_TXI_2), U$2.6
D5: IC4.7 (A6), U$1.P$28 (D5)
D5_HV: B4.HV3 (HV_RXI_2), IC4.13 (B6)
D5_LV: B4.LV3 (LV_RXO_2), U$2.7
D6: IC4.8 (A7), U$1.P$24 (D6)
D6_HV: B4.HV2 (HV_RXI_1), IC4.12 (B7)
D6_LV: B4.LV2 (LV_RXO_1), U$2.8
D7: IC4.9 (A8), U$1.P$20 (D7)
D7_HV: B4.HV1 (HV_TXO_1), IC4.11 (B8)
D7_LV: B4.LV1 (LV_TXI_1), U$2.9/CS
DATA_BUS_ENABLE_: IC1.8 (O), IC4.19 (G)
DATA_BUS_ENABLE_HV_FROM_TEENSY: B2.HV2 (HV_RXI_1), IC1.4 (I0)
DATA_BUS_ENABLE_LV: B2.LV2 (LV_RXO_1), U$2.24
FLIPFLOP_CLR: B2.HV1 (HV_TXO_1), IC5.1 (CLR), IC5.13 (CLR)
FLIPFLOP_CLR_LV: B2.LV1 (LV_TXI_1), U$2.25
FLIPFLOP_PRE: B1.HV1 (HV_TXO_1), IC5.4 (PRE), IC5.10 (PRE)
FLIPFLOP_PRE_LV: B1.LV1 (LV_TXI_1), U$2.29
GND: B1.GND1 (GND), B1.GND2 (GND), B2.GND1 (GND), B2.GND2 (GND), B3.GND1 (GND), B3.GND2 (GND), B4.GND1 (GND), B4.GND2 (GND), B5.GND1 (GND), B5.GND2 (GND), B6.GND1 (GND), B6.GND2 (GND), C1.1, C2.1, C4.1, C5.1, C6.1, C7.1, C9.-, C10.-, C11.2, H1.P1, H2.P1, H3.P1, H4.P1, IC1.7 (GND), IC2.1 (OC), IC2.10 (GND), IC3.7 (GND), IC4.10 (GND), IC5.7 (GND), IC9.2 (GND), IC10.1 (I), IC10.3 (I), IC10.7 (GND), J1.1, J1.2, RGB_LED1.3 (GND), RGB_LED2.3 (GND), U$1.P$8 (GND), U$1.P$29 (GND2), U$1.P$37 (GND3), U$2.AGND, U$2.GND, U$2.GND2, U$2.GND3, U$2.UGND1, U$2.UGND2
INTERRUPT: B1.HV2 (HV_RXI_1), IC1.10 (I1), IC1.11 (O), IC2.11 (ENC), IC5.3 (CLK), IC5.11 (CLK)
INTERRUPT_LV: B1.LV2 (LV_RXO_1), U$2.28
unnamed: U$2.3V3_LO, U$2.AREF
unnamed: IC10.9 (I), U$1.P$10 (A14)
unnamed: IC3.1 (I0), IC10.10 (O)
unnamed: IC3.2 (I1), IC10.8 (O)
unnamed: R1.1, U$2.23/A9
unnamed: R2.1, U$2.22/A8
unnamed: IC1.12 (I0), IC3.8 (O)
unnamed: IC3.3 (I2), IC10.6 (O)
unnamed: R3.1, U$2.21/A7
unnamed: R1.2, RGB_LED1.1 (BLUE)
unnamed: C9.+, IC9.1 (VI), S1.3 (S)
unnamed: B3.HV4 (HV_TXO_2), IC4.18 (B1)
unnamed: R2.2, RGB_LED1.2 (GREEN)
unnamed: R3.2, RGB_LED1.4 (RED)
unnamed: R4.1, U$2.20/A6
unnamed: R5.1, U$2.19/A5/SCL
unnamed: R6.1, U$2.18/A4/SDA
unnamed: R4.2, RGB_LED2.1 (BLUE)
unnamed: R5.2, RGB_LED2.2 (GREEN)
unnamed: R6.2, RGB_LED2.4 (RED)
unnamed: J1.3, S1.2
unnamed: B3.HV3 (HV_RXI_2), IC4.17 (B2)
unnamed: IC1.13 (I1), U$1.P$1 (RAS*)
RDX_OR_WRX_AND_DATA_BUS_ENABLE_FROM_TEENSY: IC1.9 (I0), IC10.12 (O)
RDX_OR_WRX_AND_DATA_BUS_ENABLE_FROM_TEENSY_: IC1.6 (O), IC10.13 (I)
RD_: B1.HV4 (HV_TXO_2), IC1.1 (I0), IC4.1 (DIR), IC5.12 (D), U$1.P$15 (RD*)
RD_LV_: B1.LV4 (LV_TXI_2), U$2.26
READ_OR_WRITE: IC1.3 (O), IC1.5 (I1)
VCC: B1.HV, B2.HV, B3.HV, B4.HV, B5.HV, B6.HV, C1.2, C2.2, C4.2, C5.2, C6.2, C7.2, C10.+, C11.1, IC1.14 (VCC), IC2.20 (VCC), IC3.14 (VCC), IC4.20 (VCC), IC5.2 (D), IC5.14 (VCC), IC9.3 (VO), IC10.14 (VCC), U$2.VIN
VCC/2: B1.LV, B2.LV, B3.LV, B4.LV, B5.LV, B6.LV, U$2.3V3_2
WAIT_: IC5.6 (!Q), U$1.P$33 (WAIT*)
WR_: B1.HV3 (HV_RXI_2), IC1.2 (I1), U$1.P$13 (WR*)
WR_HV: B2.HV4 (HV_TXO_2), IC5.9 (Q)
WR_LV: B2.LV4 (LV_TXI_2), U$2.10/CS
WR_LV_: B1.LV3 (LV_RXO_2), U$2.27

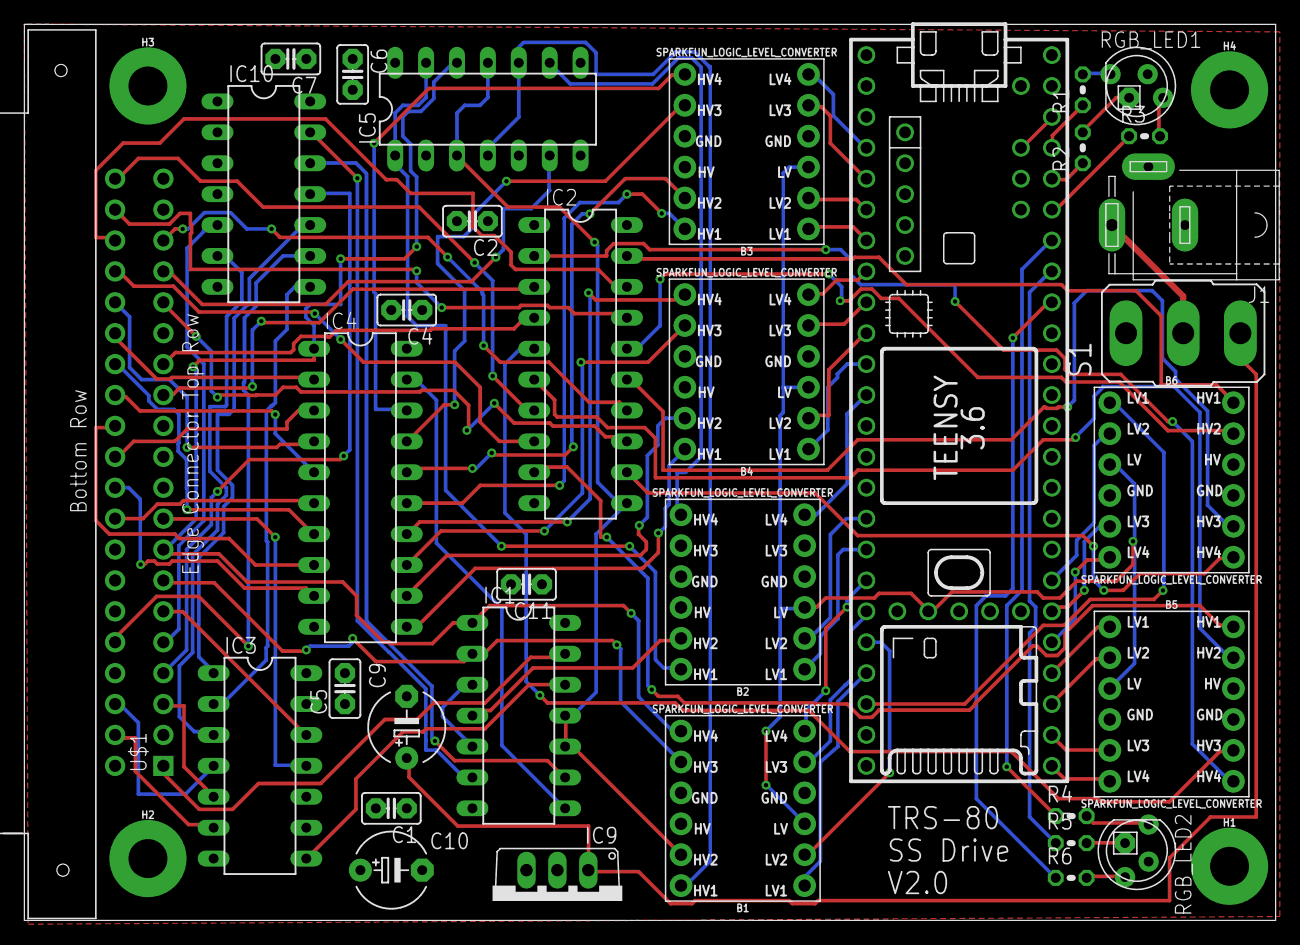
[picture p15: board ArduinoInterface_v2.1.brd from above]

Board: 2 copper layers, 102.8 x 73.6 mm, 38 parts (0 on the bottom side), 98 nets.

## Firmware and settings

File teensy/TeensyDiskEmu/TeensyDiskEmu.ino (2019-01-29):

//for use with TRSHDD board v4

#include <BlockDriver.h>
#include <FreeStack.h>
#include <MinimumSerial.h>
#include <SdFat.h>
#include <SdFatConfig.h>
#include <sdios.h>
#include <SysCall.h>
#include <StringStream.h>
#include <stdarg.h>
#include "defines.h"


extern drivesettings Drives[4];
extern volatile int interruptStatus;


volatile int iBusDirection = 2;
volatile int dataBus;
volatile int address;



/* set up pin directionality */
void pinSetup() {
  pinMode(LED1_RED, OUTPUT);
  pinMode(LED1_GREEN, OUTPUT);
  pinMode(LED1_BLUE, OUTPUT);
  pinMode(LED2_RED, OUTPUT);
  pinMode(LED2_GREEN, OUTPUT);
  pinMode(LED2_BLUE, OUTPUT);
  pinMode(INTERUPT_TO_TRS80, OUTPUT);
  pinMode(FF_CLR, OUTPUT);
  pinMode(FF_PRE, OUTPUT);
  pinMode(_37E0RD, INPUT);
  pinMode(_37E0WR, INPUT);
  pinMode(_37E4RD, INPUT);
  pinMode(_37E4WR, INPUT);
  pinMode(_37E8RD, INPUT);
  pinMode(_37E8WR, INPUT);
  pinMode(_37ECRD, INPUT);
  pinMode(_37ECWR, INPUT);
  pinMode(_A0, INPUT);
  pinMode(_A1, INPUT);
  pinMode(NOTHING1, OUTPUT);
  pinMode(NOTHING2, OUTPUT);
  pinMode(NOTHING3, OUTPUT);
  dataBusOutFromTeensyMode();
  dataBusInToTeensyMode();
}


/* initialize output pins */
void initialPinState() {
  digitalWriteFast(INTERUPT_TO_TRS80, HIGH); // turn off TRS-80 interrupt line (it's active low)
  initFlipFlop();                            // jigger flip flop into a known state (loaded, ready for trigger)
}



IntervalTimer it;




void _37E0WRInterrupt() {
  dataBus = getDataBusValue();
  address = 0x37e0 + (GPIOC_PDIR>>8);
  PokeFromTRS80(); 
  resetWaitLatch();    
}

void _37E8WRInterrupt() {
  dataBus = getDataBusValue();
  address = 0x37e8 + (GPIOC_PDIR>>8);
  PokeFromTRS80(); 
  resetWaitLatch();
} 

void _37E4WRInterrupt() {
  dataBus = getDataBusValue();
  address = 0x37e4 + (GPIOC_PDIR>>8);
  PokeFromTRS80(); 
  resetWaitLatch();
}

void _37ECWRInterrupt() {
  dataBus = getDataBusValue();
  address = 0x37ec + (GPIOC_PDIR>>8);
  PokeFromTRS80(); 
  resetWaitLatch();
}


void _37ECRDInterrupt() {
  address = 0x37ec + (GPIOC_PDIR>>8);
  setDataBus(PeekFromTRS80());
  resetWaitLatch();
}

void _37E8RDInterrupt() {
  address = 0x37e8 + (GPIOC_PDIR>>8);
  setDataBus(PeekFromTRS80());
  resetWaitLatch();
}

void _37E4RDInterrupt() {
  address = 0x37e4 + (GPIOC_PDIR>>8);
  setDataBus(PeekFromTRS80());
  resetWaitLatch();
}

void _37E0RDInterrupt() {
  address = 0x37e0 + (GPIOC_PDIR>>8);
  setDataBus(PeekFromTRS80());
  resetWaitLatch();  
}



/* wire up the interrupts */
void configureInterrupts() {
  attachInterrupt(digitalPinToInterrupt(_37ECRD), _37ECRDInterrupt, FALLING);
  attachInterrupt(digitalPinToInterrupt(_37E8RD), _37E8RDInterrupt, FALLING);
  attachInterrupt(digitalPinToInterrupt(_37E4RD), _37E4RDInterrupt, FALLING);
  attachInterrupt(digitalPinToInterrupt(_37E0RD), _37E0RDInterrupt, FALLING);

  attachInterrupt(digitalPinToInterrupt(_37ECWR), _37ECWRInterrupt, FALLING);
  attachInterrupt(digitalPinToInterrupt(_37E8WR), _37E8WRInterrupt, FALLING);
  attachInterrupt(digitalPinToInterrupt(_37E4WR), _37E4WRInterrupt, FALLING);
  attachInterrupt(digitalPinToInterrupt(_37E0WR), _37E0WRInterrupt, FALLING);
}


/* initialize everything */
void setup() {
  int iLEDCtr = 0; 
  
  cli();                              // turn off interrupts during setup()
    
  Serial.begin(2000000);              // high speed serial over USB
  pinSetup();                         // set pin modes
  initialPinState();                  // put pins in initial configuration

  L1_RED();
  L2_RED();
  while(!Serial && iLEDCtr < 30) {    // attempt to establish serial connection from Teensy
    iLEDCtr++;
    delay(100);
    L2_YELLOW();
    delay(100);
    L2_RED();
  }

  if(!Serial) {                       // couldn't establish serial connection within 6 seconds ((100+100)*30 milliseconds)
    L2_YELLOW();
    L1_YELLOW();
  }
  else {                              // okay, serial established, let's move on
    L2_CYAN();
    L1_CYAN();
  }
  
  configureInterrupts();                             // tie interrupt lines to code blocks
  openDiskFileByName("NEWDOS_80sssd_jv1.DSK",0);                 // open file specified from SD card
  openDiskFileByName("more-arcade-1_80sssd_jv1.DSK",1);                 // open file specified from SD card
  openDiskFileByName("more-arcade-2_80sssd_jv1.DSK",2);                 // open file specified from SD card
  openDiskFileByName("more-arcade-3_80sssd_jv1.DSK",3);                 // open file specified from SD card
  
  p((char*)"\nReady.\n");
  if(!Serial) {
    L2_YELLOW();                     // unable to communicate over serial, show L2 as yellow
    L1_GREEN();
  }
  else {
    L1_GREEN();                      // all good to go
    L2_GREEN();
  }

  init1771Emulation();

  p((char*)"Setting up interval timer: %d", it.begin(clockTick, 25000));
   
  sei();                             // enable interrupts
}


void clockTick() {
  // comment out if you want to turn off the clock functionality...
  interruptStatus = interruptStatus | 0x80;
  digitalWriteFast(INTERUPT_TO_TRS80,LOW);
}


String sCommand;
String sWorkBuffer;
int dNum;
boolean bInsideUploadCommand = false;
String sFileName;

void handleUploadProcess() {
  if(bInsideUploadCommand == false) {
   // we are preparing to upload a file... get ready to write file
   sFileName = sCommand.substring(strlen("upload ")).trim();
   sWorkBuffer = "";
   if(fileExists((char*)sFileName.c_str()) )
      p((char*)"ERROR: file already exists.");
   else {
     p((char*)"ready\n\n");
     dNum = 0;
     bInsideUploadCommand = true;
   }
   return;
  }
  else {
    if(sCommand.indexOf("done ") == 0) {
      bInsideUploadCommand = false;
      //TODO: add checksum code here...
      p((char*)"ok\n\n");
      return;
    }
    if(sCommand.indexOf("chunk ") == 0) {
      sCommand = sCommand.substring(6).trim();
      String chkSum = sCommand.substring(0,8);
      sCommand = sCommand.substring(8).trim();
      sWorkBuffer = sCommand; 
    }
    else {
      sWorkBuffer += sCommand;
    }

    if(sWorkBuffer.indexOf("$$$") == -1) return;
      
    sWorkBuffer = sWorkBuffer.substring(0,sWorkBuffer.length()-3);
    
    size_t buflen;
    sWorkBuffer = sWorkBuffer.replace("~","\n");
    char* buf = base64Decode((char*)sWorkBuffer.c_str(), sWorkBuffer.length(), &buflen);
    if(buf == NULL) {
      p((char*)"ERROR: problem decoding chunk\n\n");
      bInsideUploadCommand = false;
      return;      
    }
    dNum++;
    
    //TODO:  add checksum code here...
    if(buflen > 0) { 
        //p("%d ",buflen);
        appendBufferToFile(buf, buflen, (char*)sFileName.c_str());
        if(dNum % 2 == 0) {
           L2_GREEN();
        }
        else {
           L2_YELLOW();
        }
    }
    else {
      L2_BLACK();
    }

    free(buf);
 
    p((char*)"ready\n\n"); 
  }
}



void loop() { 

   while (Serial.available() > 0 ) {
       sCommand = Serial.readString().trim();
       if(!bInsideUploadCommand)
           p((char*)"\nReceived command:  >>%s<<\n\n",sCommand.c_str());
       
       if(sCommand.indexOf("mount ") != -1) {
           sCommand = sCommand.substring(sCommand.indexOf("mount ") + 6);
           dNum = sCommand.substring(0,2).toInt();
           sCommand = sCommand.substring(2);
           p((char*)"Mounting disk image file: >>%s<< on drive %d\n",sCommand.c_str(),dNum);
           openDiskFileByName(sCommand,dNum);
           init1771Emulation();
           p((char*)"\n");
       }

       if(sCommand.indexOf("catalog") != -1) {
          catalog();
          p((char*)"\n\n");
       }

       if(sCommand.indexOf("show mounts") != -1) {
          for(int i=0;i<4;i++) {
            p((char*)"%d. %s\n",i,Drives[i].sDiskFileName.c_str());
          }
          p((char*)"\n");
       }

       if(sCommand.indexOf("rm ") == 0) {
         sCommand = sCommand.substring(3);
         if(delFile((char*)sCommand.c_str()))
             p((char*)"ok\n\n");
         else
             p((char*)"ERROR: file not deleted\n\n");
       }

       if(sCommand.indexOf("view ") == 0) {
         sCommand = sCommand.substring(5);
         viewFile((char*)sCommand.c_str(),false);
         p((char*)"\n\n");         
       }

       if(sCommand.indexOf("viewhex ") == 0) {
         sCommand = sCommand.substring(8);
         viewFile((char*)sCommand.c_str(),true);
         p((char*)"\n\n");         
       }

       if(sCommand.indexOf("help") != -1) {
           p((char*)"mount\n");
           p((char*)"show mounts\n");
           p((char*)"catalog\n");
           p((char*)"upload\n");
           p((char*)"rm\n");
           p((char*)"view\n");
           p((char*)"viewhex\n");
           p((char*)"help\n"); 
           p((char*)"\n");      
       }

       if(sCommand.indexOf("upload") != -1 || bInsideUploadCommand == true) {
          handleUploadProcess();
       }
   }
}

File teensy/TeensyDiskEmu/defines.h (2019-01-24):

#define L1_RED()    {digitalWriteFast(5,HIGH);digitalWriteFast(7,LOW); digitalWriteFast(6,LOW);}
#define L1_GREEN()  {digitalWriteFast(5,LOW); digitalWriteFast(7,LOW); digitalWriteFast(6,HIGH);}
#define L1_BLUE()   {digitalWriteFast(5,LOW); digitalWriteFast(7,HIGH);digitalWriteFast(6,LOW);}
#define L1_YELLOW() {digitalWriteFast(5,HIGH);digitalWriteFast(7,LOW); digitalWriteFast(6,HIGH);}
#define L1_CYAN()   {digitalWriteFast(5,LOW); digitalWriteFast(7,HIGH);digitalWriteFast(6,HIGH);}
#define L1_VIOLET() {digitalWriteFast(5,HIGH);digitalWriteFast(7,HIGH);digitalWriteFast(6,LOW);}
#define L1_WHITE()  {digitalWriteFast(5,HIGH);digitalWriteFast(7,HIGH);digitalWriteFast(6,HIGH);}
#define L1_BLACK()  {digitalWriteFast(5,LOW); digitalWriteFast(7,LOW); digitalWriteFast(6,LOW);}

#define L2_RED()    {digitalWriteFast(2,HIGH);digitalWriteFast(4,LOW); digitalWriteFast(3,LOW);}
#define L2_BLUE()   {digitalWriteFast(2,LOW); digitalWriteFast(4,HIGH);digitalWriteFast(3,LOW);}
#define L2_GREEN()  {digitalWriteFast(2,LOW); digitalWriteFast(4,LOW); digitalWriteFast(3,HIGH);}
#define L2_CYAN()   {digitalWriteFast(2,LOW); digitalWriteFast(4,HIGH);digitalWriteFast(3,HIGH);}
#define L2_VIOLET() {digitalWriteFast(2,HIGH);digitalWriteFast(4,HIGH);digitalWriteFast(3,LOW);}
#define L2_YELLOW() {digitalWriteFast(2,HIGH);digitalWriteFast(4,LOW); digitalWriteFast(3,HIGH);}
#define L2_WHITE()  {digitalWriteFast(2,HIGH);digitalWriteFast(4,HIGH);digitalWriteFast(3,HIGH);}
#define L2_BLACK()  {digitalWriteFast(2,LOW); digitalWriteFast(4,LOW); digitalWriteFast(3,LOW);}


//                        0 - disconnected
//                        1 - disconnected
#define LED2_RED          2 /* PORTD BIT 0 */
#define LED2_GREEN        3 /* PORTA BIT 12 */
#define LED2_BLUE         4 /* PORTA BIT 13 */
#define LED1_RED          5 /* PORTD BIT 7 */
#define LED1_GREEN        6 /* PORTD BIT 4 */
#define LED1_BLUE         7 /* PORTD BIT 2 */

#define INTERUPT_TO_TRS80 8 /* PORTD BIT 3 */

#define D3                9 /* PORTC BIT 3 */
#define D4               10 /* PORTC BIT 4 */
#define D6               11 /* PORTC BIT 6 */
#define D7               12 /* PORTC BIT 7 */
#define D5               13 /* PORTC BIT 5 */
//                       14 - disconnected
#define D0               15 /* PORTC BIT 0 */
//                       16 - disconnected
//                       17 - disconnected
//                       18 - disconnected
//                       19 - disconnected
//                       20 - disconnected
//                       21 - disconnected
#define D1               22 /* PORTC BIT 1 */
#define D2               23 /* PORTC BIT 2 */
//                       24 - disconnected
#define FF_CLR           25 /* PORTA BIT 5 */
#define _37ECRD          26 /* PORTA BIT 14 */
#define _37E0WR          27 /* PORTA BIT 15 */
#define _37E4WR          28 /* PORTA BIT 16 */
#define FF_PRE           29 /* PORTB BIT 18 */
#define _37E8RD          30 /* PORTB BIT 19 */
#define _37E0RD          31 /* PORTB BIT 10 */
#define _37E4RD          32 /* PORTB BIT 11 */
#define _37E8WR          33 /* PORTE BIT 24 */
#define _37ECWR          34 /* PORTE BIT 25 */
#define _A0              35 /* PORTC BIT 8 */
#define _A1              36 /* PORTC BIT 9 */
#define NOTHING1         37 /* PORTC BIT 10 */
#define NOTHING2         38 /* PORTC BIT 11 */
#define NOTHING3         39 /* PORTA BIT 17 */

#define IN 0
#define OUT 1

typedef struct  {
   volatile int trackNum=0;
   volatile int sectorNum=0;
   volatile int dataRegister=0;
   volatile int commandRegister;
   volatile int statusRegister;
   volatile int byteCtr = 0;
   volatile int afterSectorBusyCtr = 0;
   volatile int busyCtr = 0;
   volatile int DRQCtr = 0;

   volatile int iIndexHole = 1;
   volatile int iTrackDirection = IN;
   volatile int motorRunningCtr;

   volatile int sectorsRead = 0;
   volatile int statusRegisterChecks = 0;
   volatile int currentCommand;
   File diskFile;
   String sDiskFileName;
}
drivesettings;

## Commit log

2018-10-31 eaglecad drawings
    [ArduinoInterface.brd, ArduinoInterface.sch, ArduinoInterface_v2.brd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]
2018-10-31 teensy code - initial
2018-10-31 teensy code
2018-12-17 changes to Teensy code
2018-12-17 TeensyDiskEmu update
2018-12-18 updating schematics
    [ArduinoInterface_v2.1.brd, ArduinoInterface_v2.1.sch, ArduinoInterface_v3.brd]
2018-12-18 updated schematic to fix 74LS241/74LS244 mixup
    [ArduinoInterface_v3.brd, ArduinoInterface_v3.sch]
2018-12-24 updating code to current state - sort of working, RD* side seems to be working, WR* side not quite
    [ArduinoInterface_v3.sch]
2018-12-28 updated code... working... sort of
    [ArduinoInterface_v4.brd, ArduinoInterface_v4.sch]
2019-01-04 current work v3.0 code
2019-01-05 updates to v4 schematic
    [ArduinoInterface_v4.brd, ArduinoInterface_v4.sch]
2019-01-11 update for v3.1 of schematic
    [ArduinoInterface_v4.brd, ArduinoInterface_v4.sch]
2019-01-13 fix for status register differences
    [TeensyDiskEmu.ino]
2019-01-13 adding trs-80 schematic
2019-01-14 update for v4.1 of board and current code
    [ArduinoInterface_v4.1.brd, ArduinoInterface_v4.1.sch]
2019-01-16 current state, stable but a little buggy, almost boots successfully
    [TeensyDiskEmu.ino, defines.h]
2019-01-19 current status, almost working
    [ArduinoInterface_v5.sch]
2019-01-27 schematic changes
    [ArduinoInterface_v4.1.brd, ArduinoInterface_v4.2.brd, ArduinoInterface_v4.2.sch]
2019-01-28 Added Mac utility for manipulating TRS80HDD over USB (mount files, catalog disk images, etc.)

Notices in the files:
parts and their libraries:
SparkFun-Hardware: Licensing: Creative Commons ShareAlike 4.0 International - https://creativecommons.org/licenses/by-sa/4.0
